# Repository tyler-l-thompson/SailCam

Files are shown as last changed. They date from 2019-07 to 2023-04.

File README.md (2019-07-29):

# Description

The SailCam is an attempt to put an entirly self sufficent camera on a sail boat. The camera mounts to the stern rail of the boat and does not require an external power source. It powers itself entirely from solar energy and a battery pack.

The current design sacrifices elegance for modularity and brute force functionality. It is divided into components that can be individually detached and redesigned if needed. This allows for design iteration over a testing period. A new design will be created after core functionality is refined. 

# Video Results

All timelapse videos processed from the pictures taken by the SailCam can be found [here](https://photos.app.goo.gl/NxdoZSaHQNxRXsou5)

## Port Huron to Mackinac Race 2019
https://youtu.be/PzzFX_mOYdo

# Specifications

Battery Capacity: 33600 mAh <br>
Solar Panel Output (Per panel): 4V 400mA <br>
Image Capture Interval: 20 seconds <br>
Storage Capacity: up to 32 GB <br>

# Parts
Camera Module: ArduCAM Mini 5MP Plus OV5642 <br>
CPU: Arduino Mini Pro ATMega328 16MHz 3.3V <br>
SD Card Module: LC Studio SPI SD Card Socket Reader/Writer <br>
Real Time Clock: DS3231 <br>
Power Controller: TP4056 <br>
Batteries: 14500 3.7V 2800mAH Lithium Li-ion

# Build
## Main Board
Front of the main board without the SD card module attached<br>

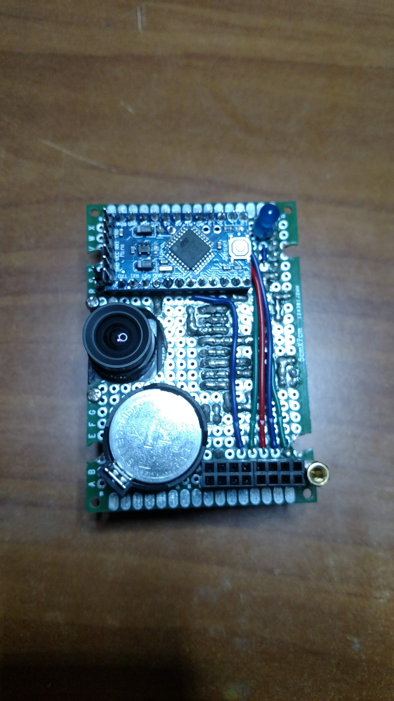
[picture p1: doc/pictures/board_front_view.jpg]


Back of the main board<br>

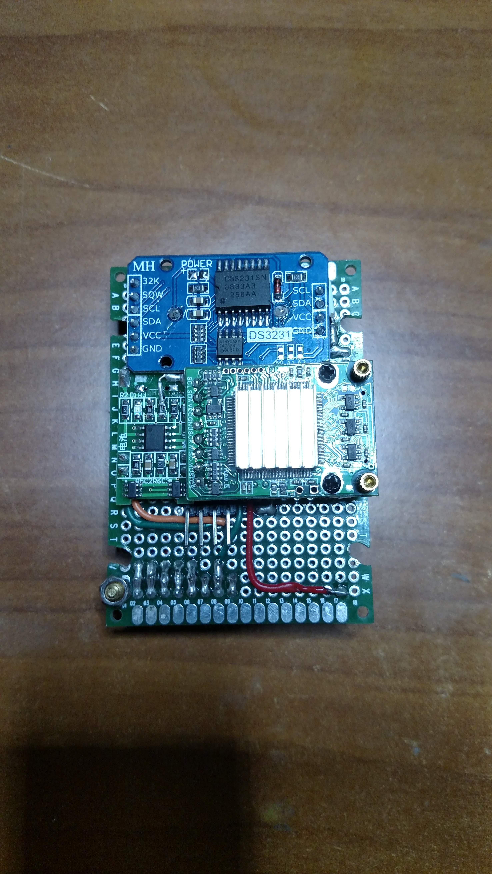
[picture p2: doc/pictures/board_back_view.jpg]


Side view<br>

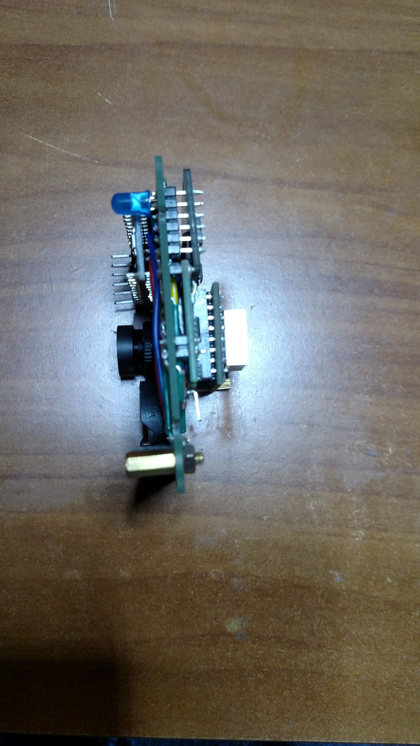
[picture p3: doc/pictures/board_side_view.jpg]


## Final Construction
Final Construction for the 2019 Mackinac Race. A lot of the chassis was 3D printed. Originally the camera module was designed to be in potrait mode, but after testing, it was changed to landscape.
<br>

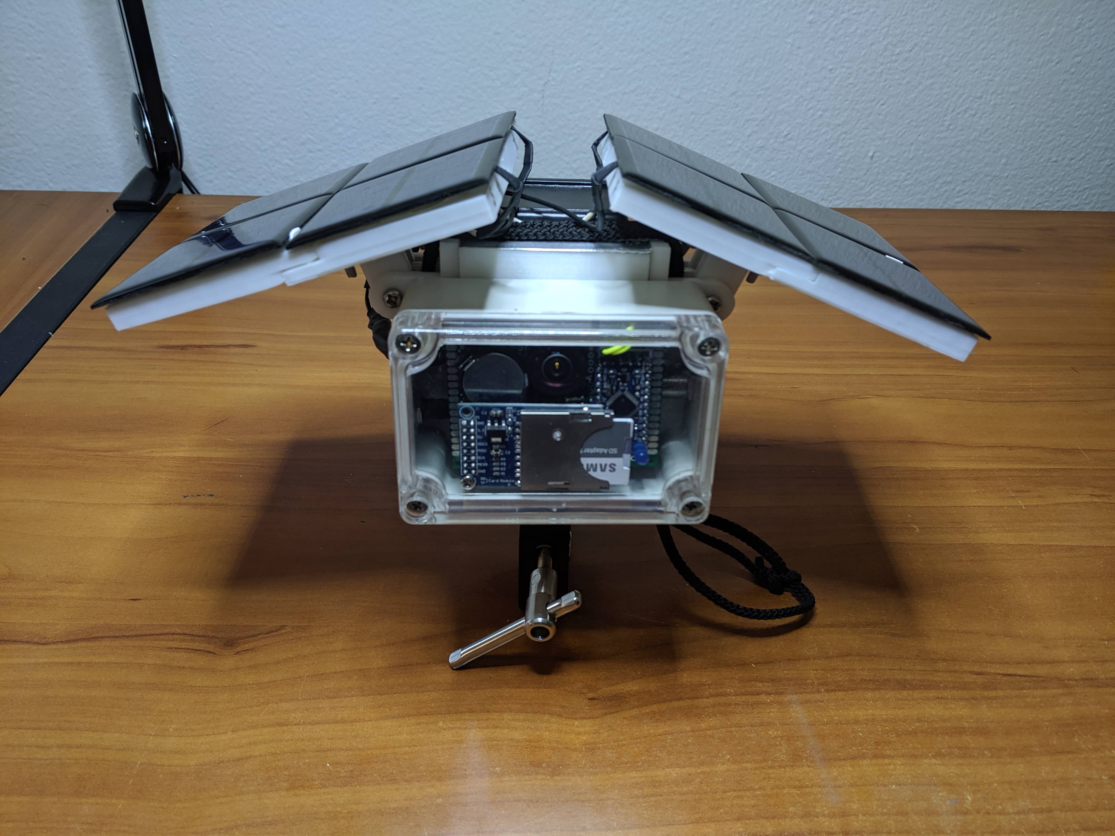
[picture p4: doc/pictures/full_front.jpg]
<br>
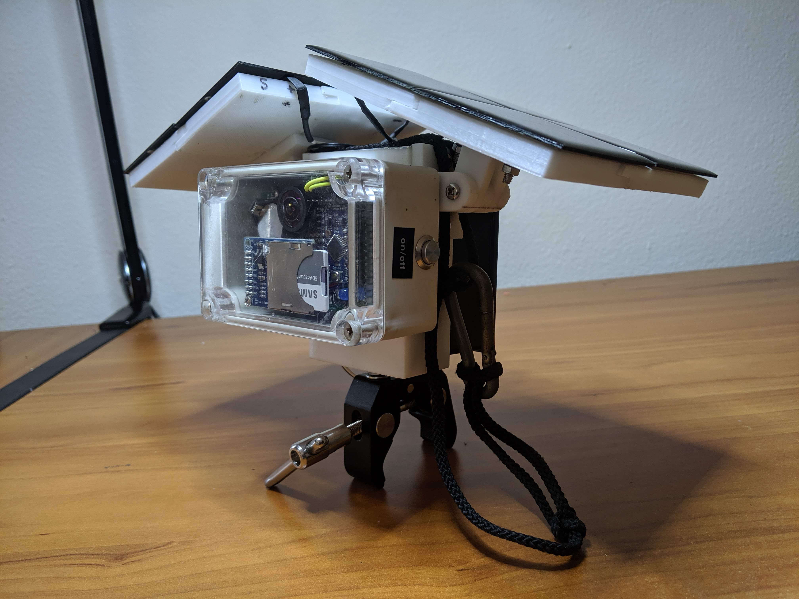
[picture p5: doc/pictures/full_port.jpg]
<br>
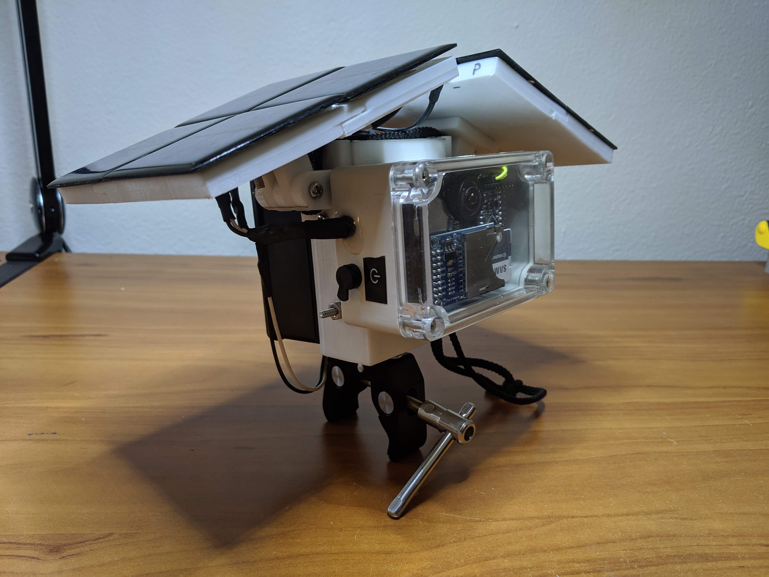
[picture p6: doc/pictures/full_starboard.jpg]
<br>

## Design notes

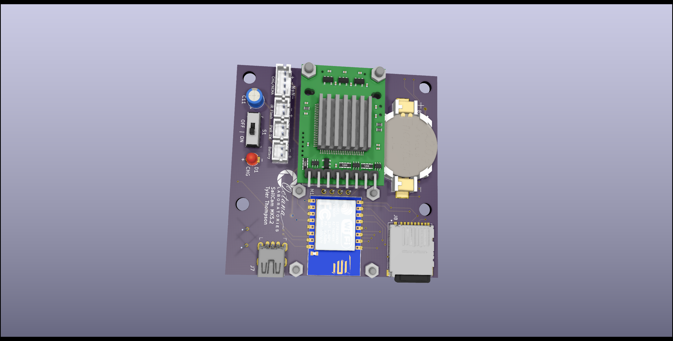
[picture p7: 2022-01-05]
doc/pictures/SailCam_MK5_back.png

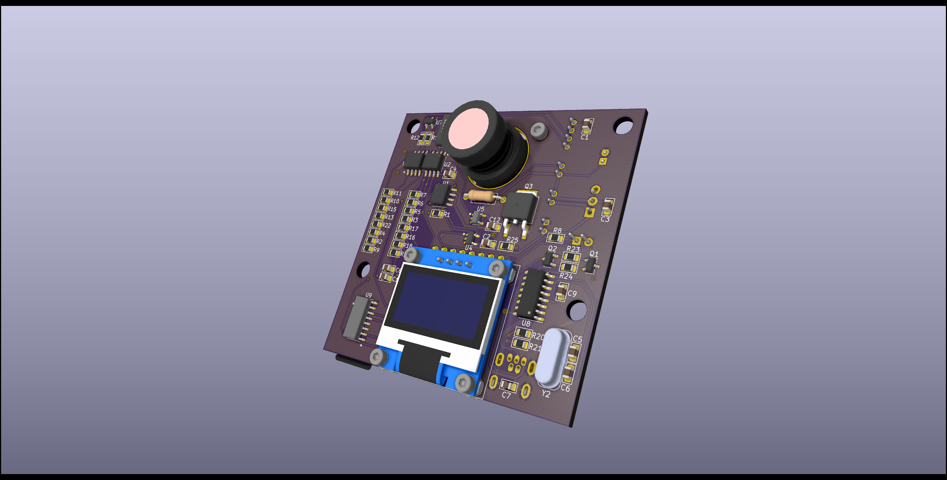
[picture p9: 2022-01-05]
doc/pictures/SailCam_MK5_front.png

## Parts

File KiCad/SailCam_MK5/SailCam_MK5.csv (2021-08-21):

Source: | C:\Users\Dexter\Documents\SailCam_MK5\SailCam_MK5\SailCam_MK5.sch
Date: | 8/5/2021 7:54:40 PM
Tool: | Eeschema (5.1.5)-3
Component Count: | 66
Ref | Value | Footprint | Datasheet | Manufacturer | Vendor
B1 | BU2032SM-BT-GTR | footprints:BAT_BU2032SM-BT-GTR | https://media.digikey.com/pdf/Data%20Sheets/Memory%20Protection%20PDFs/Coin_Cell_Guide.pdf
C1 | 0.33 uF | footprints:C_0805_2012Metric_Pad1.15x1.40mm_HandSolder_FullSilk | ~
C2 | 1 uF | footprints:C_0805_2012Metric_Pad1.15x1.40mm_HandSolder_FullSilk | ~
C3 | 10 uF | footprints:C_0805_2012Metric_Pad1.15x1.40mm_HandSolder_FullSilk | ~
C4 | 10 uF | footprints:C_0805_2012Metric_Pad1.15x1.40mm_HandSolder_FullSilk | ~
C5 | 22 pF | footprints:C_0805_2012Metric_Pad1.15x1.40mm_HandSolder_FullSilk | ~
C6 | 22 pF | footprints:C_0805_2012Metric_Pad1.15x1.40mm_HandSolder_FullSilk | ~
C7 | 0.1 uF | footprints:C_0805_2012Metric_Pad1.15x1.40mm_HandSolder_FullSilk | ~
C8 | 0.1 uF | footprints:C_0805_2012Metric_Pad1.15x1.40mm_HandSolder_FullSilk | ~
C9 | 0.1 uF | footprints:C_0805_2012Metric_Pad1.15x1.40mm_HandSolder_FullSilk | ~
C10 | 0.1 uF | footprints:C_0805_2012Metric_Pad1.15x1.40mm_HandSolder_FullSilk | ~
C11 | 100 uF | Capacitor_THT:CP_Radial_D5.0mm_P2.00mm | ~
C12 | 0.1 uF | footprints:C_0805_2012Metric_Pad1.15x1.40mm_HandSolder_FullSilk | ~
D1 | LED | LED_THT:LED_D3.0mm | ~
J1 | B2B-PH-K-SLFSN | footprints:B2B-PH-K-SLFSN | https://www.jst-mfg.com/product/pdf/eng/ePH.pdf
J2 | B2B-PH-K-SLFSN | footprints:B2B-PH-K-SLFSN | https://www.jst-mfg.com/product/pdf/eng/ePH.pdf
J3 | B2B-PH-K-SLFSN | footprints:B2B-PH-K-SLFSN | https://www.jst-mfg.com/product/pdf/eng/ePH.pdf
J4 | B4B-PH-K-SLFSN | footprints:B4B-PH-K-SLFSN | https://www.jst-mfg.com/product/pdf/eng/ePH.pdf
J5 | SSW-108-02-G-S | footprints:SSW-108-02-G-S | https://www.uctronics.com/download/Amazon/B0068.pdf
J6 | SSW-104-02-G-S | footprints:SSW-104-02-G-S_OLED | http://suddendocs.samtec.com/catalog_english/ssw_th.pdf
J7 | USB_B | footprints:AMPHENOL_61729-1011BLF | https://www.amphenol-icc.com/media/wysiwyg/files/drawing/61729.pdf
J8 | DM3BT-DSF-PEJS | footprints:DM3BT-DSF-PEJS | https://www.hirose.com/product/document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
M1 | 2491 | digikey-footprints:WIFI_Module_ESP8266_2491 | https://media.digikey.com/pdf/Data%20Sheets/Adafruit%20PDFs/2491_Web.pdf | Adafruit Industries LLC
Q1 | SS8050-G | footprints:SS8050-G | https://www.digikey.com/en/htmldatasheets/production/1953165/0/0/1/ss8050-g.html
Q2 | SS8050-G | footprints:SS8050-G | https://www.digikey.com/en/htmldatasheets/production/1953165/0/0/1/ss8050-g.html
Q3 | AOD1N60 | TO228P1003X240-3N
R1 | 320 KΩ | footprints:C_0805_2012Metric_Pad1.15x1.40mm_HandSolder_FullSilk | ~
R2 | 100 KΩ | footprints:C_0805_2012Metric_Pad1.15x1.40mm_HandSolder_FullSilk | ~
R3 | 320 KΩ | footprints:C_0805_2012Metric_Pad1.15x1.40mm_HandSolder_FullSilk | ~
R4 | 100 KΩ | footprints:C_0805_2012Metric_Pad1.15x1.40mm_HandSolder_FullSilk | ~
R5 | 1 KΩ | footprints:C_0805_2012Metric_Pad1.15x1.40mm_HandSolder_FullSilk | ~
R6 | 1 KΩ | footprints:C_0805_2012Metric_Pad1.15x1.40mm_HandSolder_FullSilk | ~
R7 | 1 KΩ | footprints:C_0805_2012Metric_Pad1.15x1.40mm_HandSolder_FullSilk | ~
R8 | 1k Ω | footprints:C_0805_2012Metric_Pad1.15x1.40mm_HandSolder_FullSilk | ~
R9 | 3 KΩ | footprints:C_0805_2012Metric_Pad1.15x1.40mm_HandSolder_FullSilk | ~
R10 | 10 KΩ | footprints:C_0805_2012Metric_Pad1.15x1.40mm_HandSolder_FullSilk | ~
R11 | 10 KΩ | footprints:C_0805_2012Metric_Pad1.15x1.40mm_HandSolder_FullSilk | ~
R12 | 10 Ω | footprints:C_0805_2012Metric_Pad1.15x1.40mm_HandSolder_FullSilk | ~
R13 | 330 Ω | footprints:C_0805_2012Metric_Pad1.15x1.40mm_HandSolder_FullSilk | ~
R14 | 10 Ω | footprints:C_0805_2012Metric_Pad1.15x1.40mm_HandSolder_FullSilk | ~
R15 | 330 Ω | footprints:C_0805_2012Metric_Pad1.15x1.40mm_HandSolder_FullSilk | ~
R16 | 10 KΩ | footprints:C_0805_2012Metric_Pad1.15x1.40mm_HandSolder_FullSilk | ~
R17 | 10 KΩ | footprints:C_0805_2012Metric_Pad1.15x1.40mm_HandSolder_FullSilk | ~
R18 | 10 KΩ | footprints:C_0805_2012Metric_Pad1.15x1.40mm_HandSolder_FullSilk | ~
R19 | 10 KΩ | footprints:C_0805_2012Metric_Pad1.15x1.40mm_HandSolder_FullSilk | ~
R20 | 470 Ω | footprints:C_0805_2012Metric_Pad1.15x1.40mm_HandSolder_FullSilk | ~
R21 | 470 Ω | footprints:C_0805_2012Metric_Pad1.15x1.40mm_HandSolder_FullSilk | ~
R22 | 10 KΩ | footprints:C_0805_2012Metric_Pad1.15x1.40mm_HandSolder_FullSilk | ~
R23 | 10 KΩ | footprints:C_0805_2012Metric_Pad1.15x1.40mm_HandSolder_FullSilk | ~
R24 | 10 KΩ | footprints:C_0805_2012Metric_Pad1.15x1.40mm_HandSolder_FullSilk | ~
R25 | 1 KΩ | footprints:C_0805_2012Metric_Pad1.15x1.40mm_HandSolder_FullSilk | ~
R26 | 10 KΩ | Resistor_THT:R_Box_L8.4mm_W2.5mm_P5.08mm | ~
S1 | SW_SPST | digikey-footprints:Switch_Toggle_ATE1D-2M3-10-Z | ~
S2 | SW_Push | Button_Switch_THT:SW_PUSH_6mm | ~
S3 | SW_Push | Button_Switch_THT:SW_PUSH_6mm | ~
U1 | ADA4806-1ARJZ-R7 | footprints:ADA4806-1ARJZ-R7 | https://www.analog.com/media/en/technical-documentation/data-sheets/ADA4806-1.pdf
U2 | DS1672S-33+T&R | footprints:DS1672S-33&plus_T&R | https://datasheets.maximintegrated.com/en/ds/DS1672.pdf
U3 | NCV7805BD2TG | footprints:NCV7805BD2TG | https://www.onsemi.com/pdf/datasheet/mc7800-d.pdf
U4 | LTC4054ES5-4.2#TRMPBF | footprints:SOT95P280X100-5N | https://www.analog.com/media/en/technical-documentation/data-sheets/405442xf.pdf
U5 | XC6220B331MR-G | footprints:XC6220B331MR-G | https://media.digikey.com/pdf/Data%20Sheets/Torex/XC6220.pdf
U6 | MAX485CSA+ | footprints:MAX485CSA&plus_ | https://datasheets.maximintegrated.com/en/ds/MAX1487-MAX491.pdf
U7 | SM712.TCT | footprints:SM712.TCT | https://semtech.my.salesforce.com/sfc/p/
U8 | CH340G | Package_SO:SOIC-16_3.9x9.9mm_P1.27mm | http://www.datasheet5.com/pdf-local-2195953
U9 | MC74HC365ADG | footprints:MC74HC365ADG | https://www.onsemi.com/pdf/datasheet/mc74hc365a-d.pdf
Y1 | ABS25-32.768KHZ-6-1-T | footprints:XTAL_ABS25-32.768KHZ-6-1-T | https://abracon.com/Resonators/abs25.pdf
Y2 | ECS-120-20-4X | footprints:XTAL_ECS-120-20-4X | https://ecsxtal.com/store/pdf/hc-49usx.pdf

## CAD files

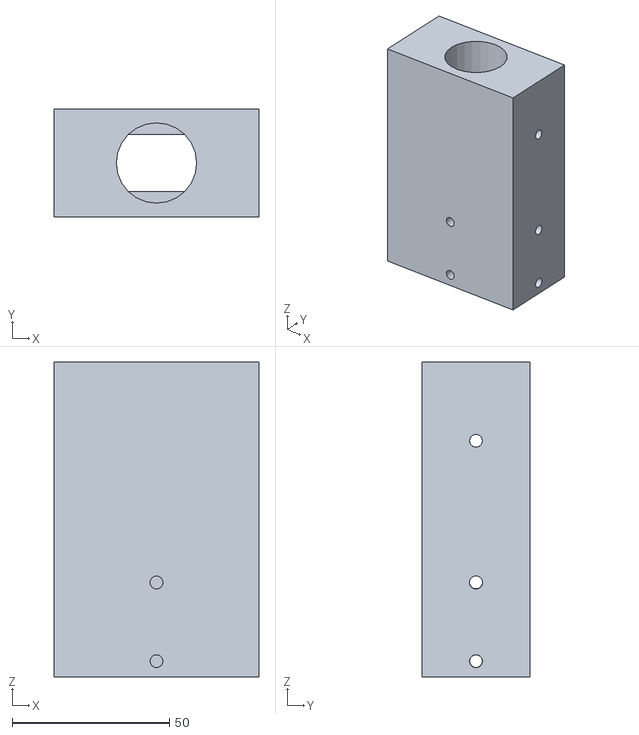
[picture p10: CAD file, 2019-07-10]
3D_Objects/main_bracket.stl
65.1 x 34.2 x 100.1

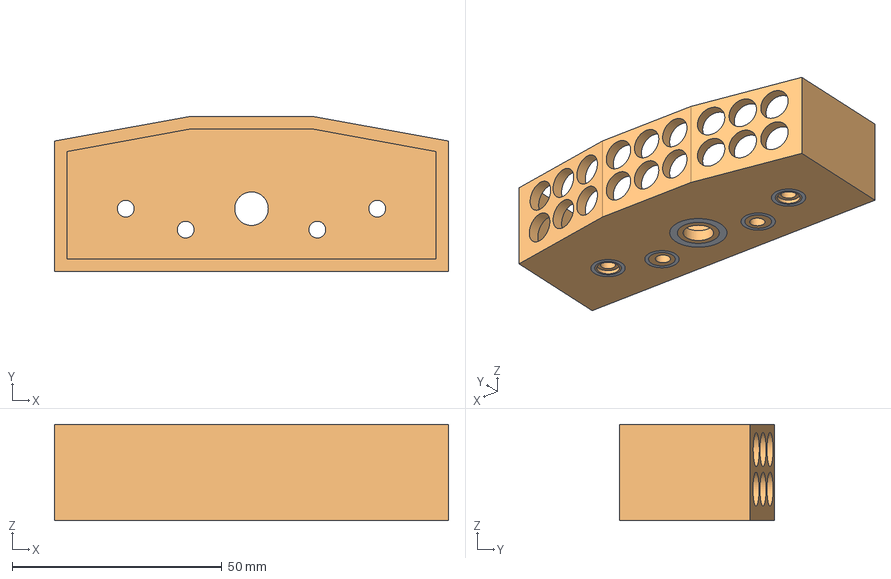
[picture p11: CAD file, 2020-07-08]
3D_Objects/ir_mount/ir_mount_base_v2.FCStd
94.0 x 37.0 x 23.0 mm

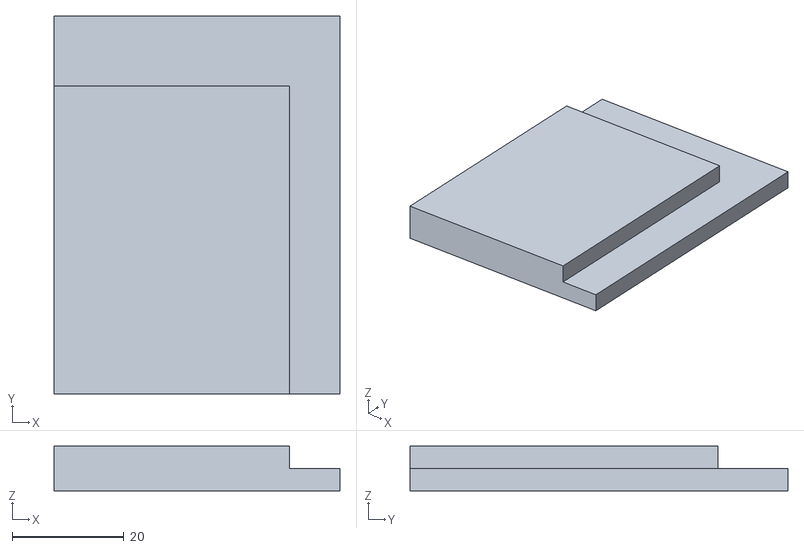
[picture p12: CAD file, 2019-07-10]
3D_Objects/panel_mount/section_2.stl
51.0 x 67.5 x 8.00

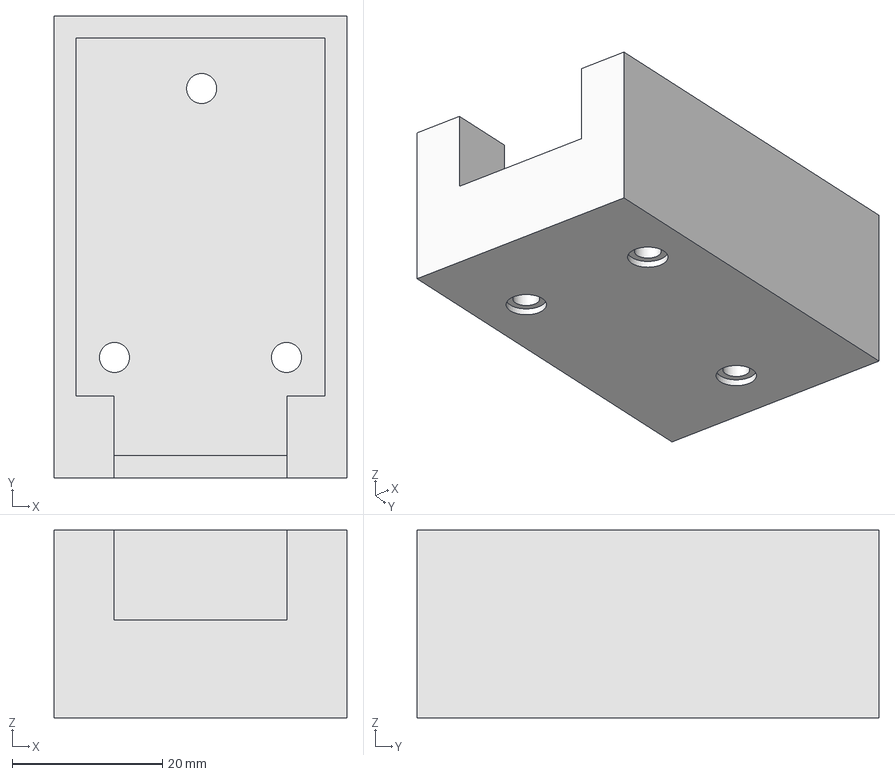
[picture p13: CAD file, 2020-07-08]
3D_Objects/power_supply/12v_stepper_case.FCStd
39.0 x 61.5 x 25.0 mm

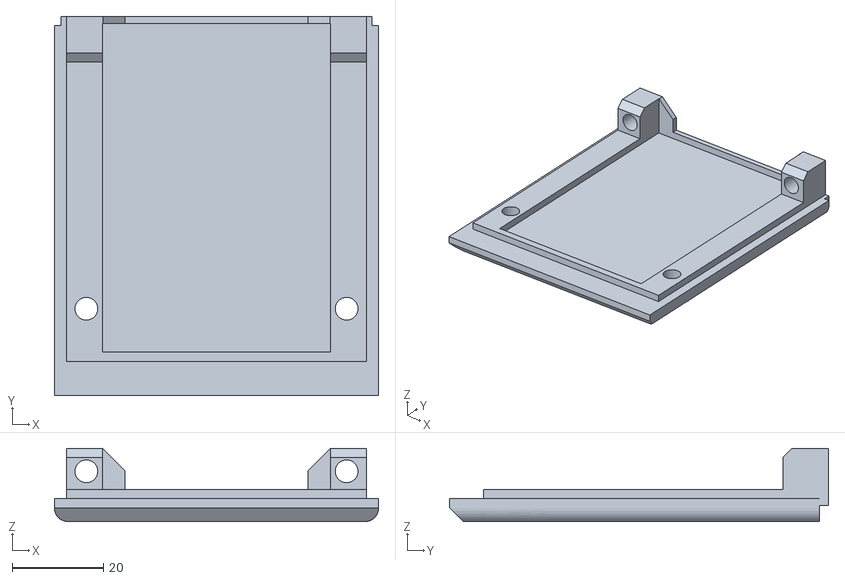
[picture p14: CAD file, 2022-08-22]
3D_Objects/SailCam_MK5/SailCamMK5_BoatCase_Back.stl
71.0 x 83.0 x 16.0

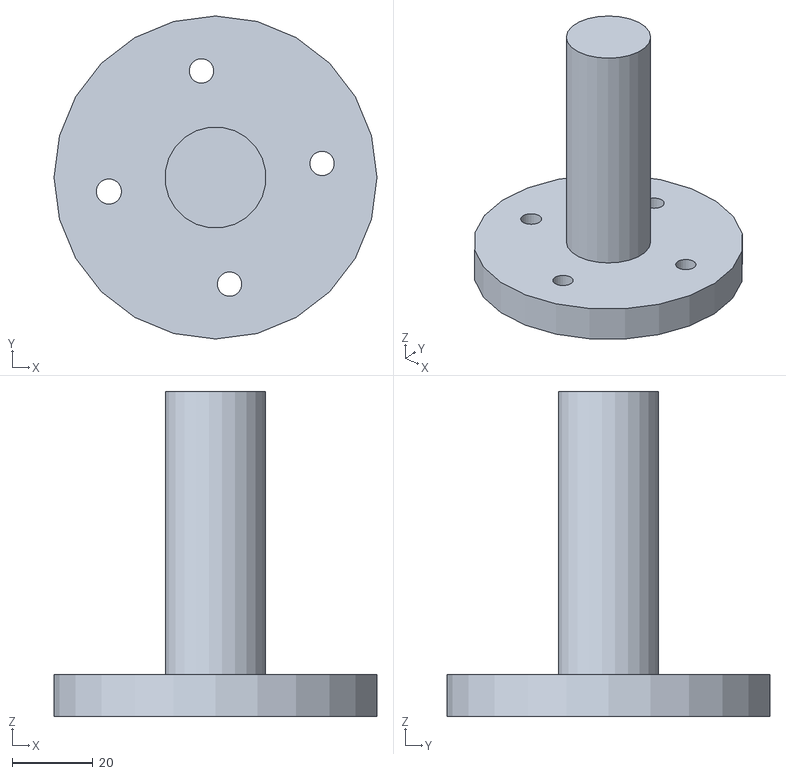
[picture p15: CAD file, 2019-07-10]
3D_Objects/stand_bracket.stl
80.1 x 80.1 x 80.6

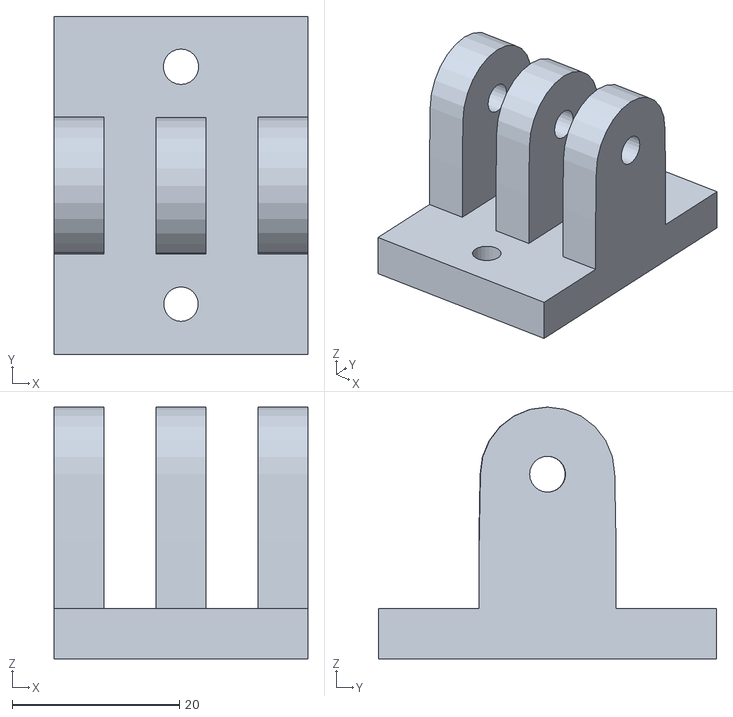
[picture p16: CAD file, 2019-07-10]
3D_Objects/bracket_bottom_v2.stl
30.3 x 40.4 x 30.1

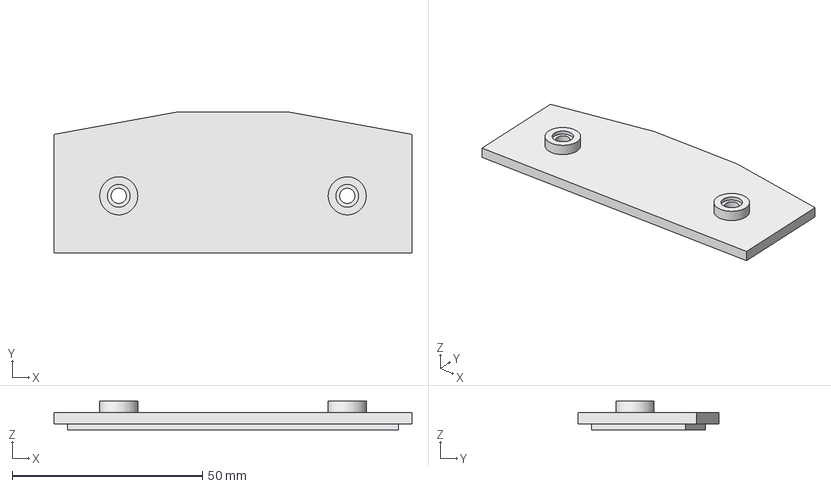
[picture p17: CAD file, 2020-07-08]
3D_Objects/ir_mount/ir_mount_cover.FCStd
94.0 x 37.0 x 7.50 mm

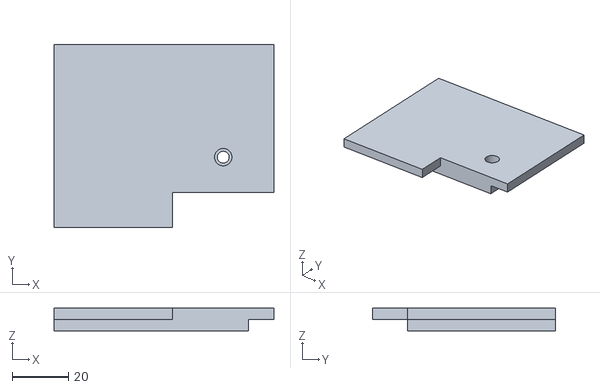
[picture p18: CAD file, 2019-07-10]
3D_Objects/panel_mount/section_3.stl
78.0 x 65.0 x 8.00

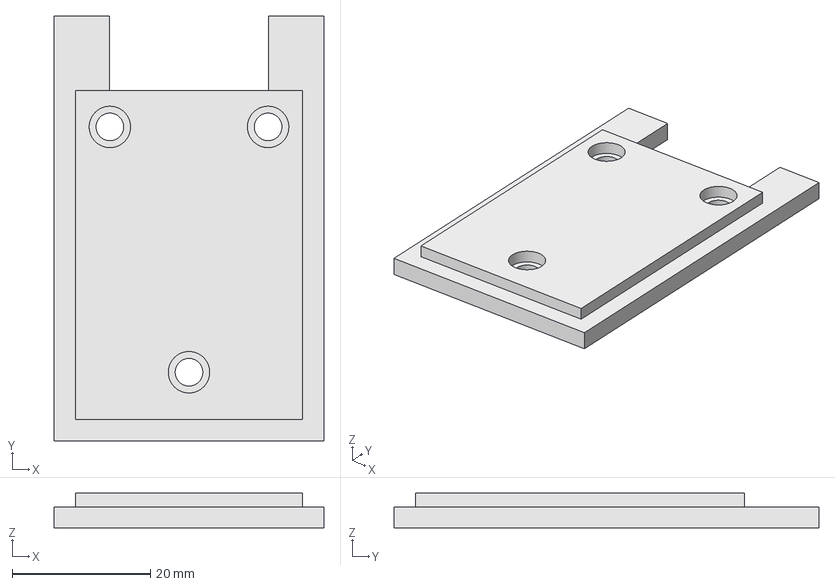
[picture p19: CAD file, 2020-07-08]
3D_Objects/power_supply/12v_stepper_case_lid.FCStd
39.0 x 61.5 x 5.00 mm

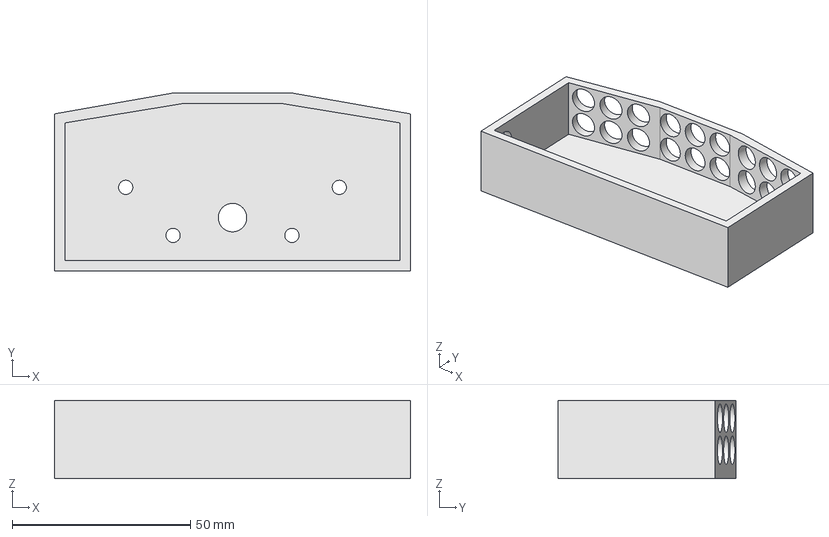
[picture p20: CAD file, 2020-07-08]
3D_Objects/ir_mount/ir_mount_base.FCStd
100.0 x 50.0 x 22.0 mm

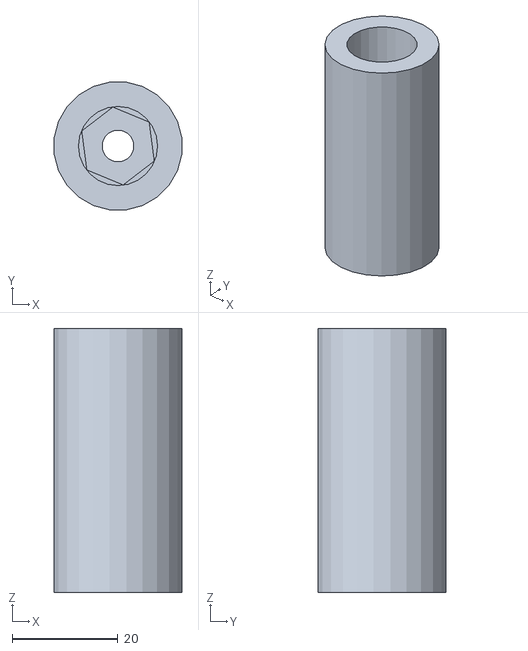
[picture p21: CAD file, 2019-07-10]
3D_Objects/mount_adapter.stl
24.2 x 24.2 x 50.0

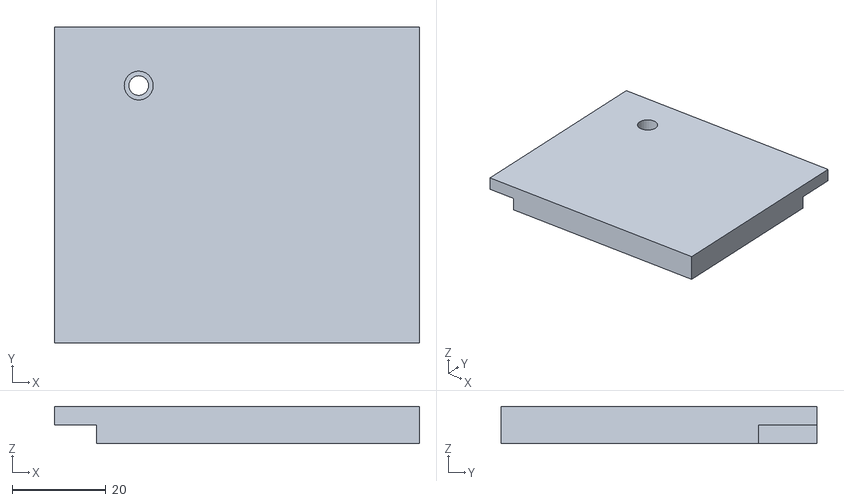
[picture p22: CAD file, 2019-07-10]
3D_Objects/panel_mount/section_1.stl
78.0 x 67.5 x 8.00

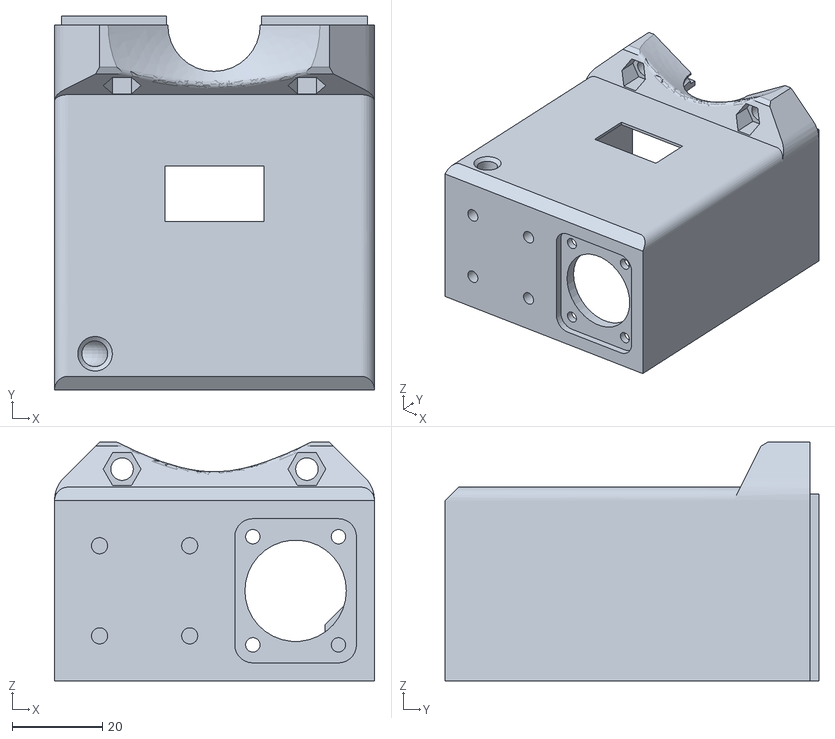
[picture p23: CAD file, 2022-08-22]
3D_Objects/SailCam_MK5/SailCamMK5_BoatCase_Bottom.stl
71.0 x 82.9 x 53.0

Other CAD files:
3D_Objects/SailCam_MK5/SailCamMK5_BoatCase_Back_Cutout.stl
3D_Objects/panel_mount/section_4.stl
3D_Objects/SailCam_MK5/SailCamMK5_BoatCase_Top.stl
3D_Objects/stand_bracket_post.stl
3D_Objects/SailCam_MK5/AAA Batterie.step
3D_Objects/SailCam_MK5/Button.FCStd
3D_Objects/SailCam_MK5/Button.step
3D_Objects/SailCam_MK5/Clamp.FCStd
3D_Objects/SailCam_MK5/Clamp.step
3D_Objects/SailCam_MK5/M3_10mm_Screw.step
3D_Objects/SailCam_MK5/M3_25mm_Screw.step
3D_Objects/SailCam_MK5/M3_6mm_Screw.step
3D_Objects/SailCam_MK5/M3_Nut.step
3D_Objects/SailCam_MK5/M3_Screw.FCStd
3D_Objects/SailCam_MK5/M4_12mm_Screw.step
3D_Objects/SailCam_MK5/M4_20mm_Screw.step
3D_Objects/SailCam_MK5/M4_24mm_Screw.step
3D_Objects/SailCam_MK5/M4_30mm_Screw.step
3D_Objects/SailCam_MK5/M4_40mm_Screw.step
3D_Objects/SailCam_MK5/M4_Nut.step
3D_Objects/SailCam_MK5/M4_Screw.FCStd
3D_Objects/SailCam_MK5/PowerConnector.FCStd
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

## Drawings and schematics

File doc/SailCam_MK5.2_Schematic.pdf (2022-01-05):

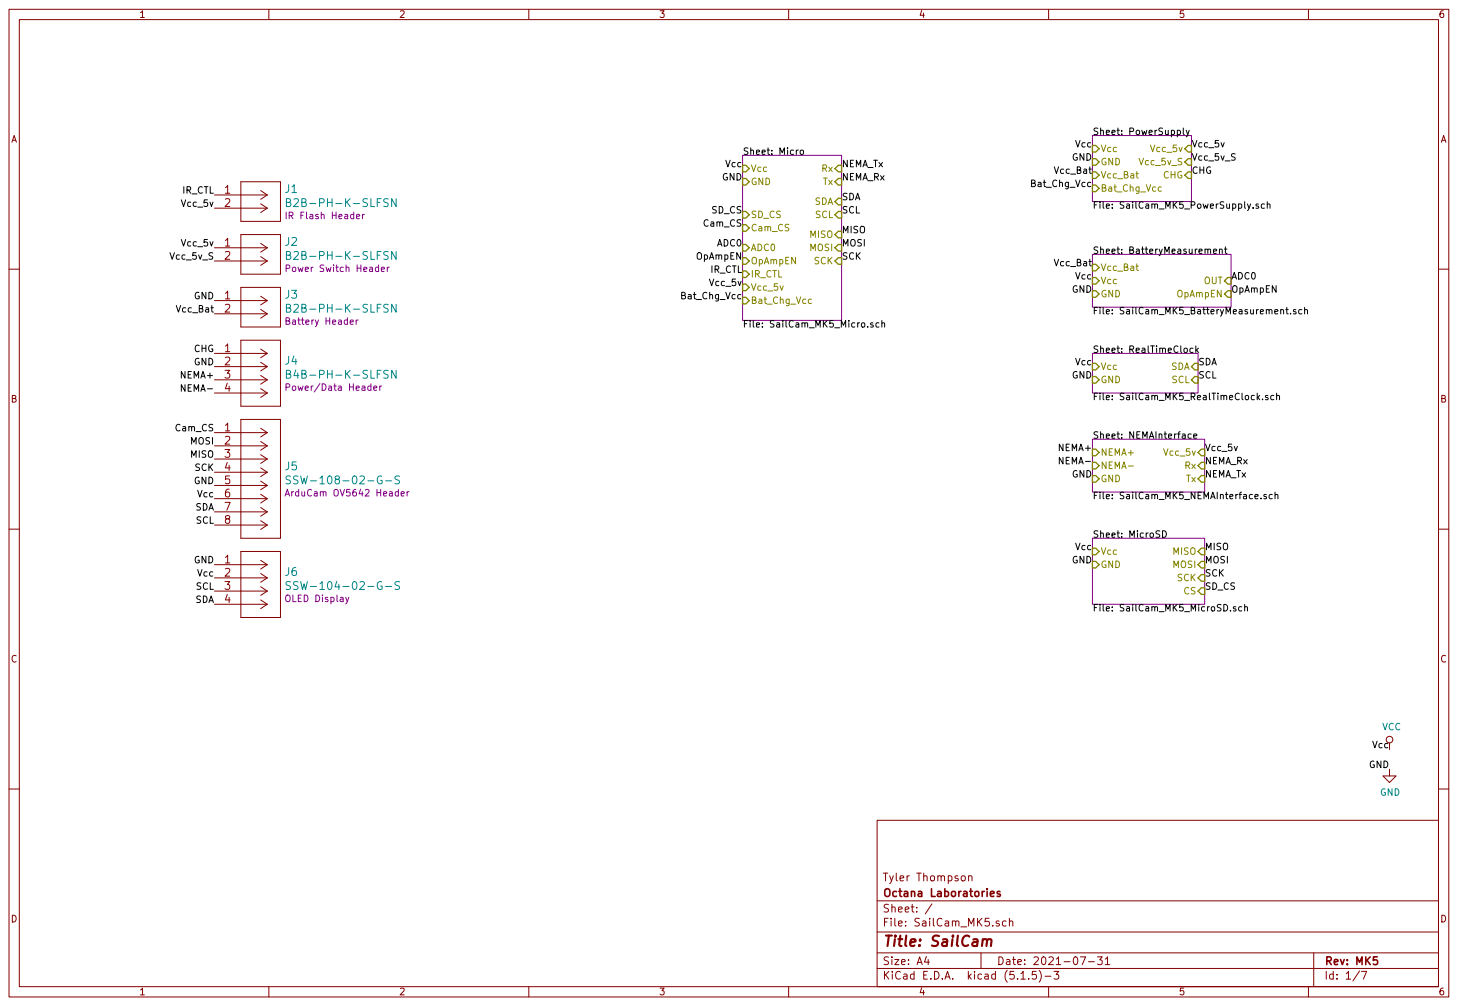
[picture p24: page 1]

Sheet: PowerSupply
File: SailCam_MK5_PowerSupply.sch Vcc GND

Sheet: Micro File: SailCam_MK5_Micro.sch Vcc GND
GND

Bat_Chg_Vcc Sheet: RealTimeClock File: SailCam_MK5_RealTimeClock.sch SDA

Vcc_5vRxTx NEMA+ NEMA- Sheet: MicroSD

File: SailCam_MK5.sch Sheet: / Octana Laboratories Tyler Thompson

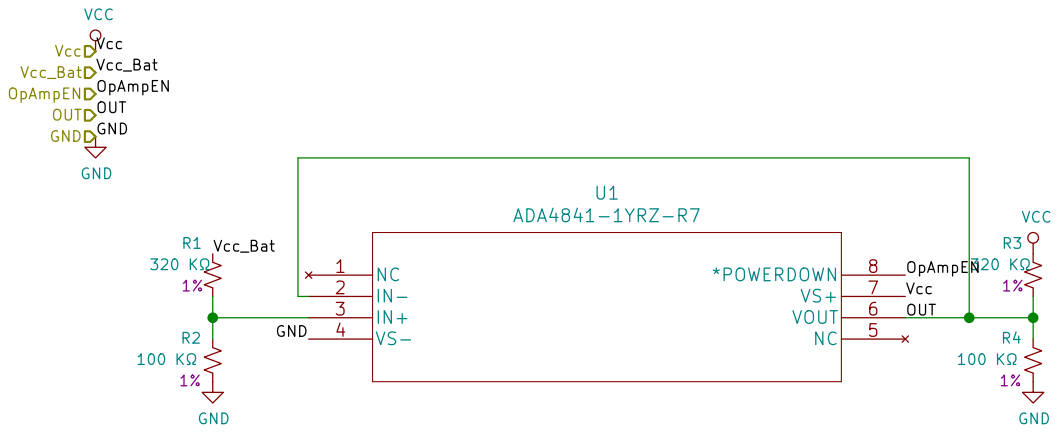
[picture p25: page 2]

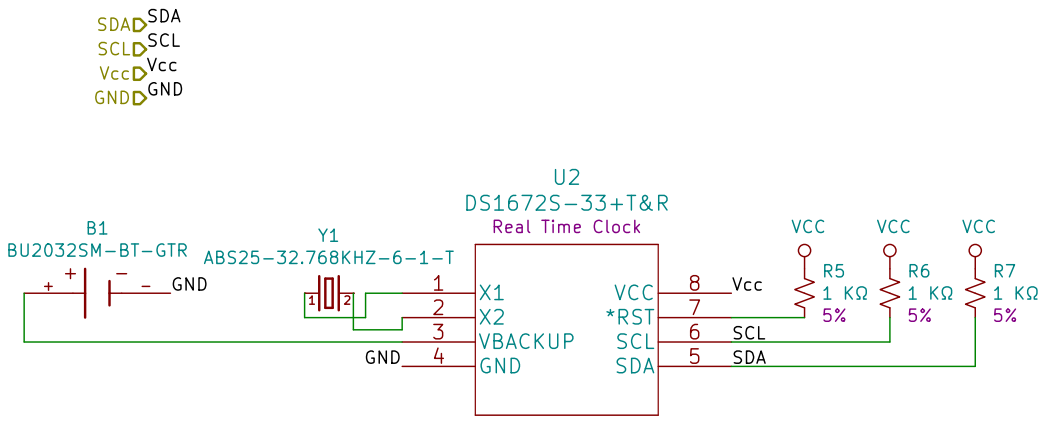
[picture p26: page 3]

File: SailCam_MK5_RealTimeClock.sch Sheet: /RealTimeClock/ Octana Laboratories Tyler Thompson

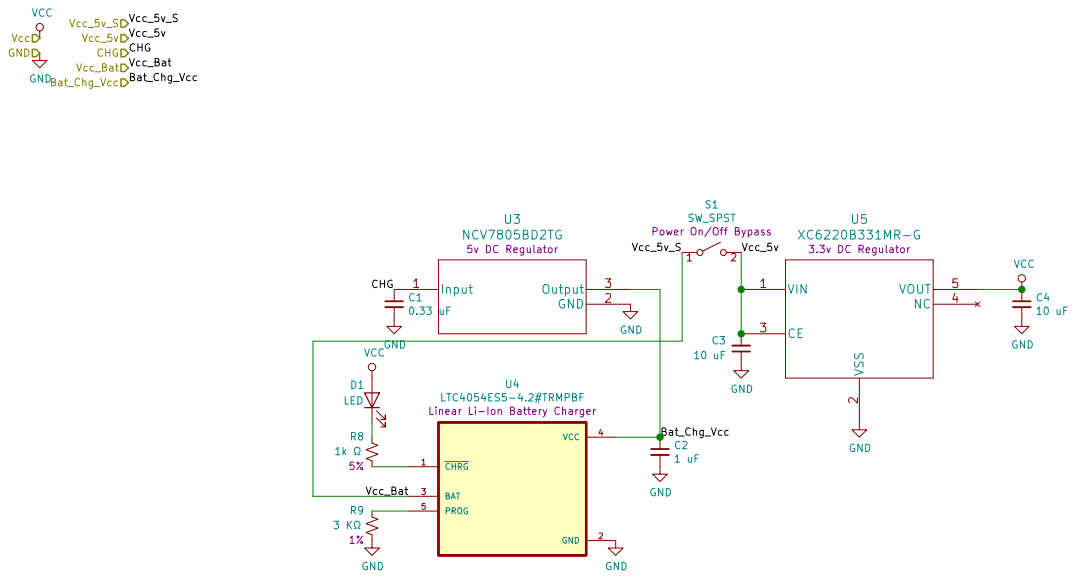
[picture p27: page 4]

Sheet: /PowerSupply/ Octana Laboratories Tyler Thompson GND GND

LED
Linear Li-Ion Battery Charger R8

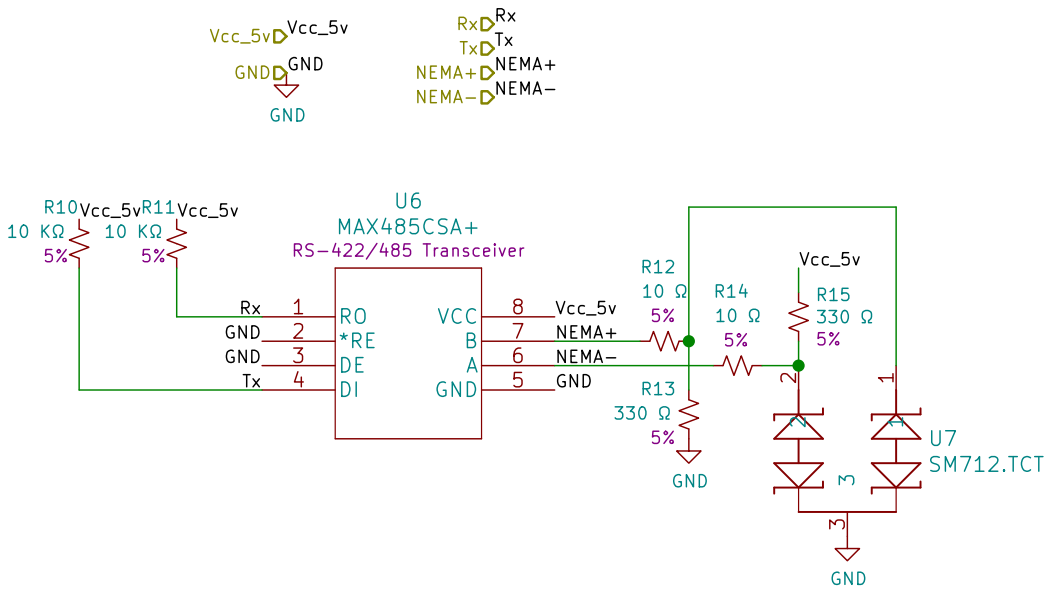
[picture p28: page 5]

File: SailCam_MK5_NEMAInterface.sch Sheet: /NEMAInterface/ Octana Laboratories Tyler Thompson

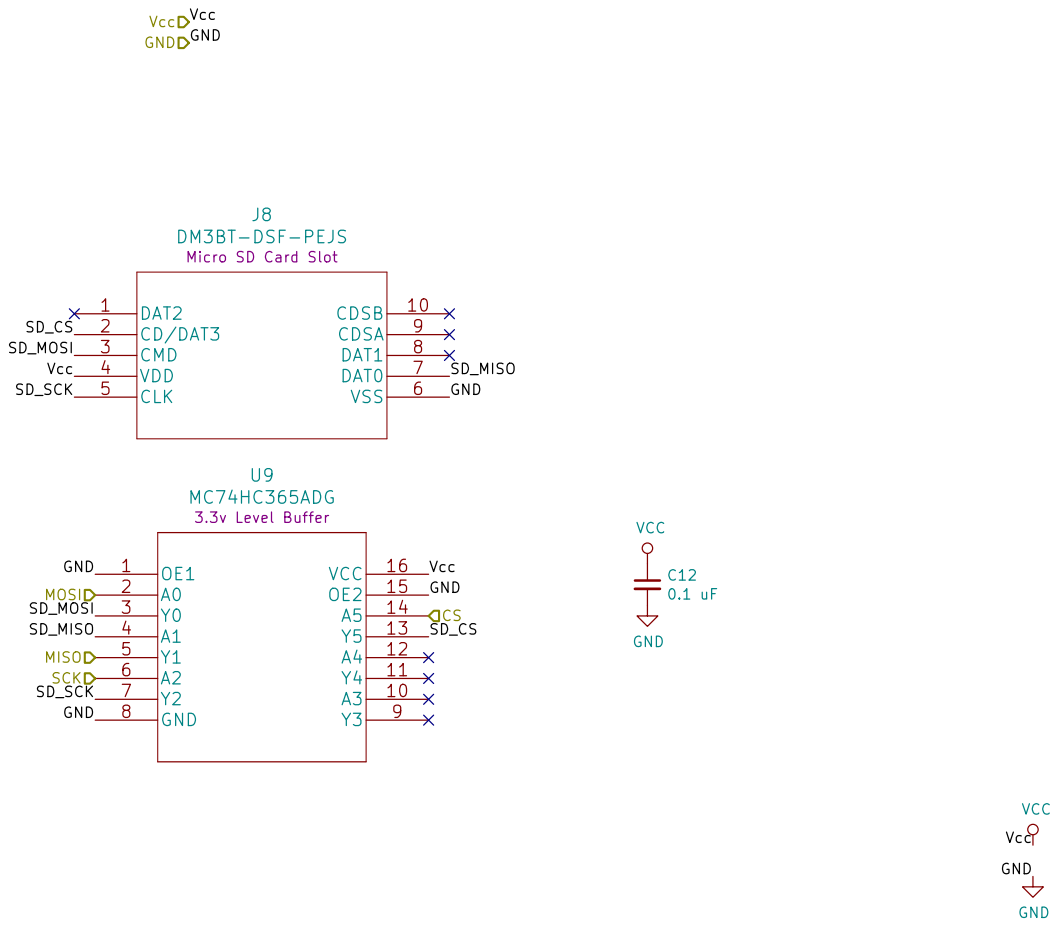
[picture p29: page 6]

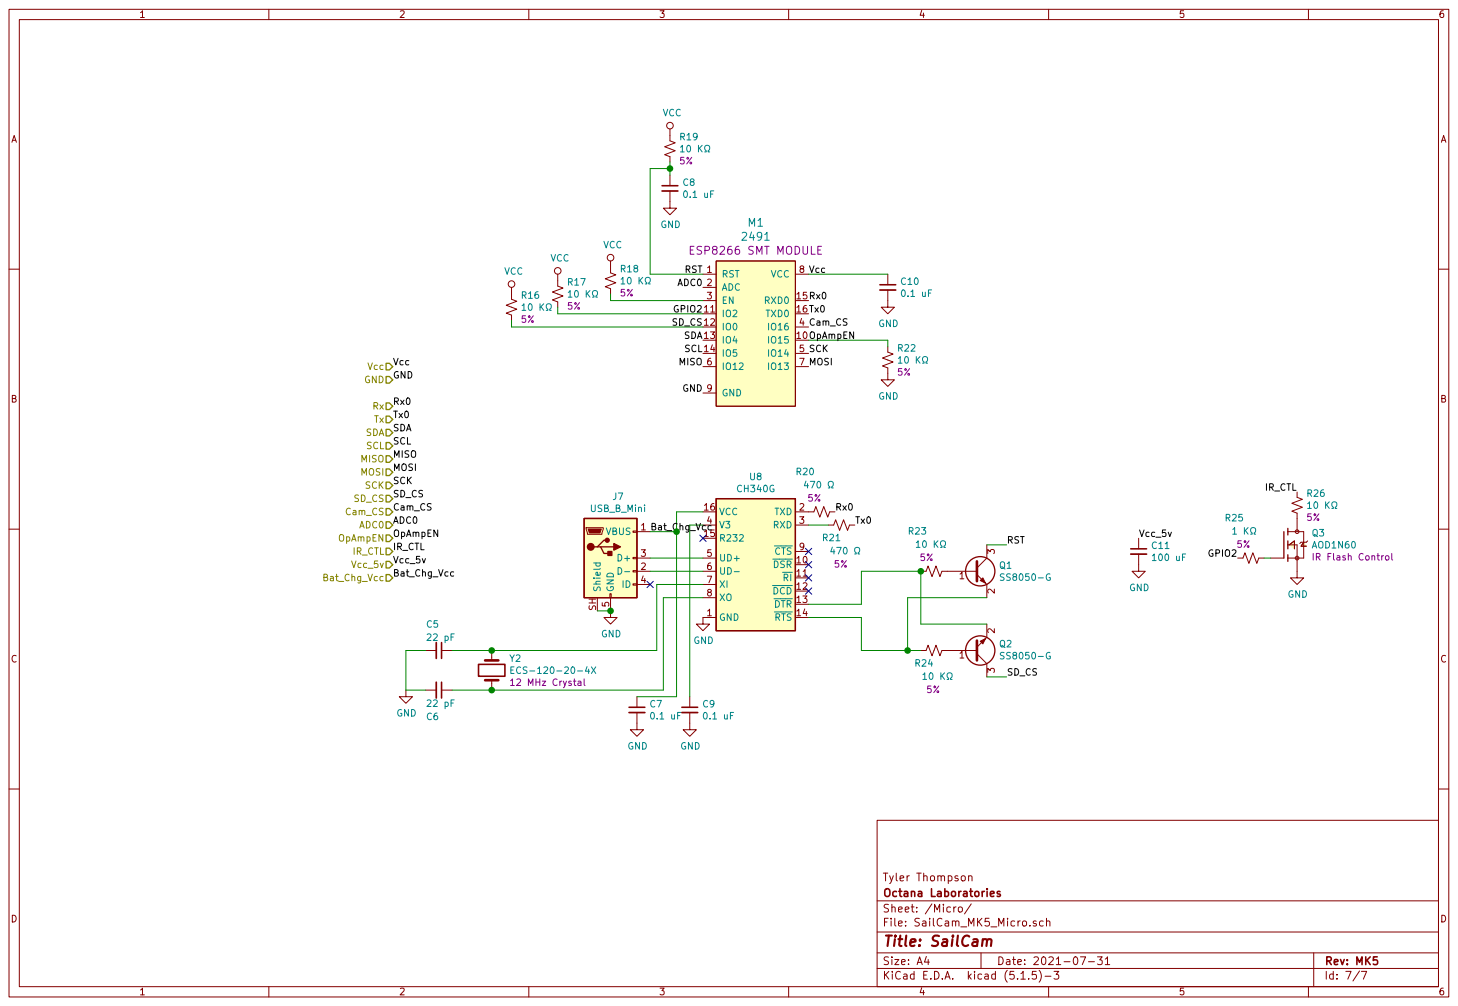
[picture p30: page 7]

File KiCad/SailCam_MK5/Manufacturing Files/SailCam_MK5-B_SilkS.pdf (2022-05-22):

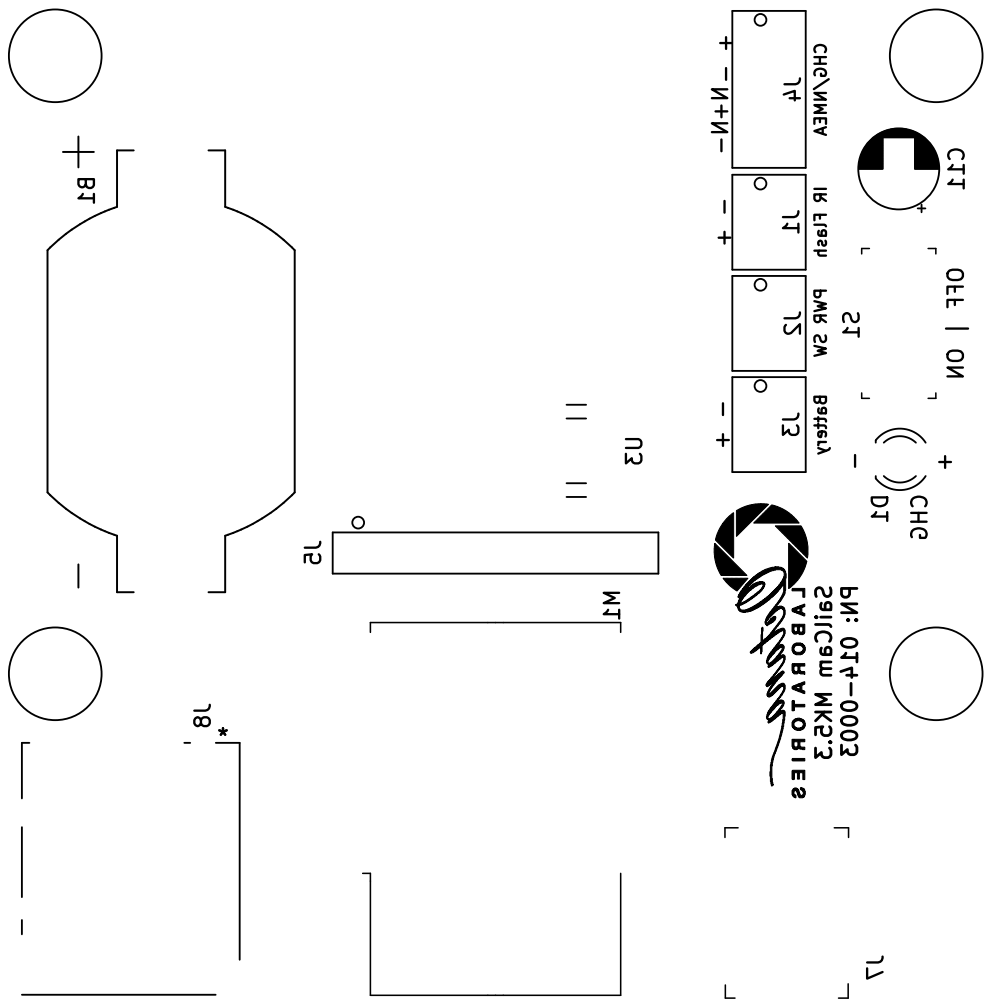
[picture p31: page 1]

SailCam MK5.3 PN: 014-0003 B1 J4 CHG/NMEA + - N+ N- J2 PWR SW J3 Battery+ - J1 IR Flash - + J7 U3 J5 M1 S1 OFF | ON D1 CHG + - C11 J8 *

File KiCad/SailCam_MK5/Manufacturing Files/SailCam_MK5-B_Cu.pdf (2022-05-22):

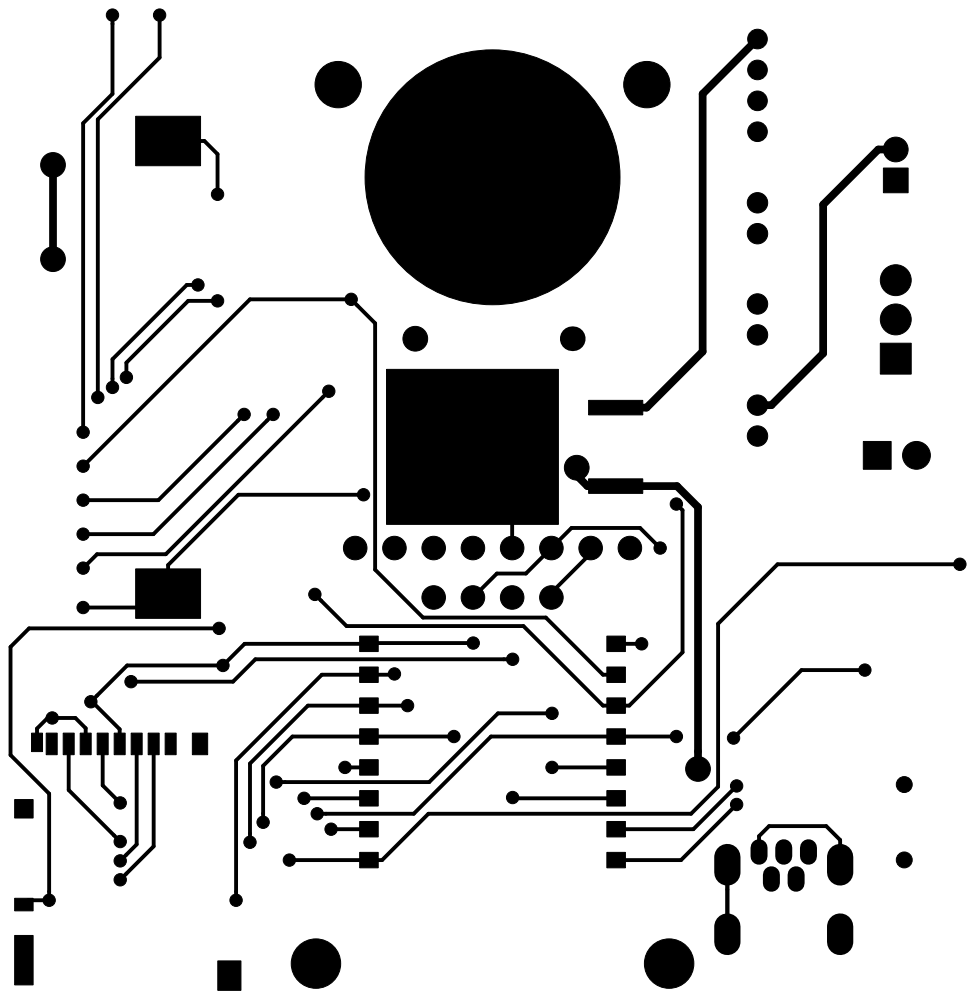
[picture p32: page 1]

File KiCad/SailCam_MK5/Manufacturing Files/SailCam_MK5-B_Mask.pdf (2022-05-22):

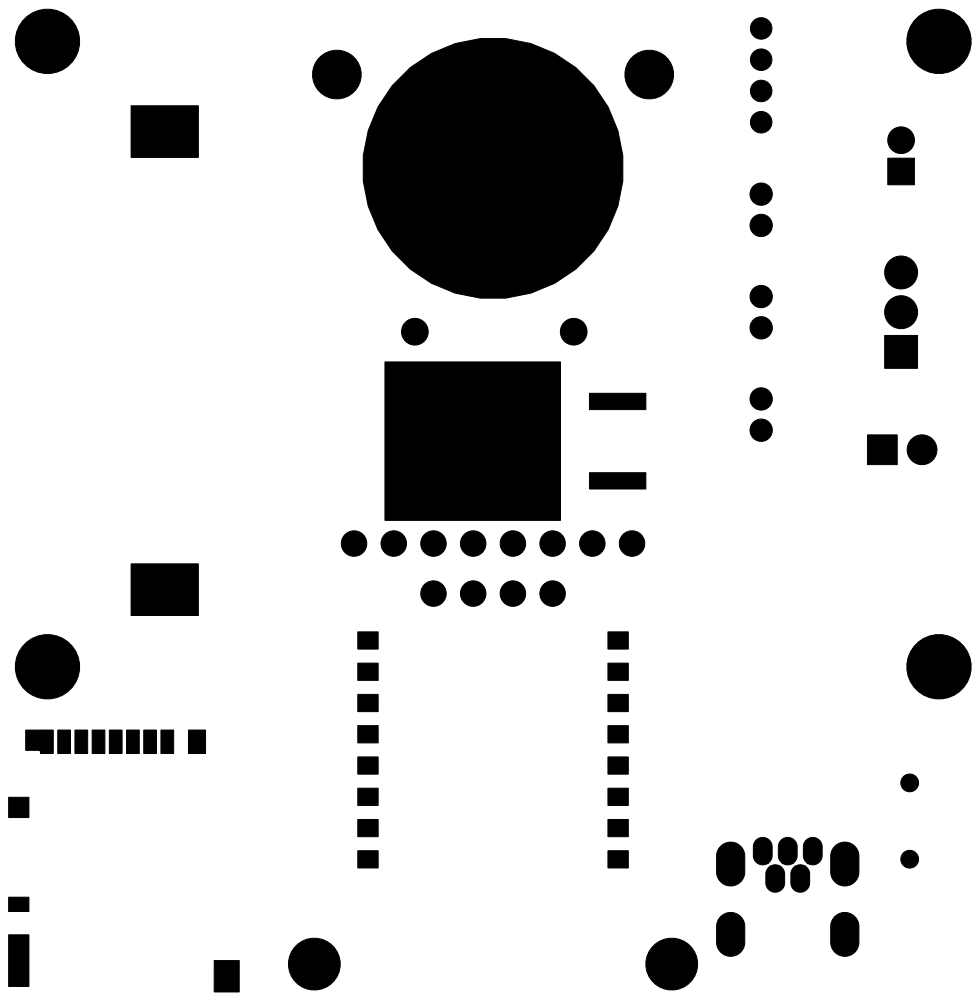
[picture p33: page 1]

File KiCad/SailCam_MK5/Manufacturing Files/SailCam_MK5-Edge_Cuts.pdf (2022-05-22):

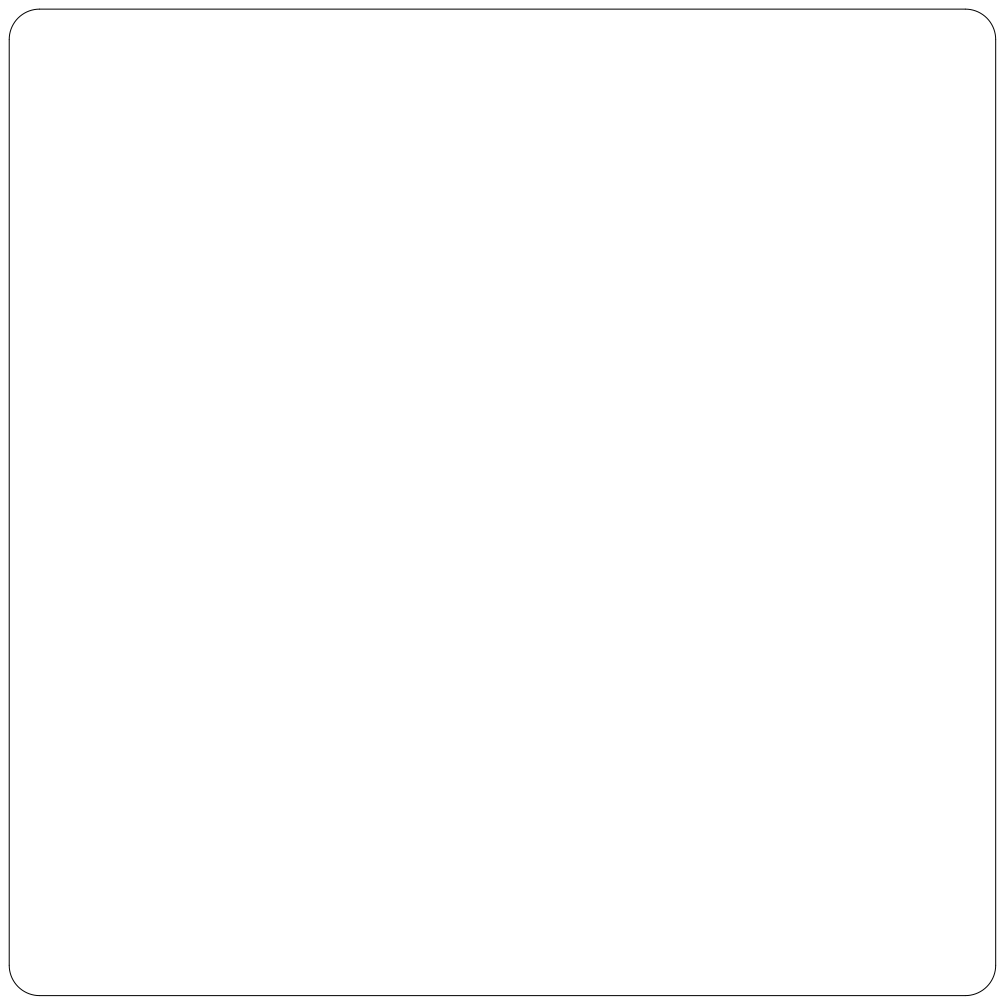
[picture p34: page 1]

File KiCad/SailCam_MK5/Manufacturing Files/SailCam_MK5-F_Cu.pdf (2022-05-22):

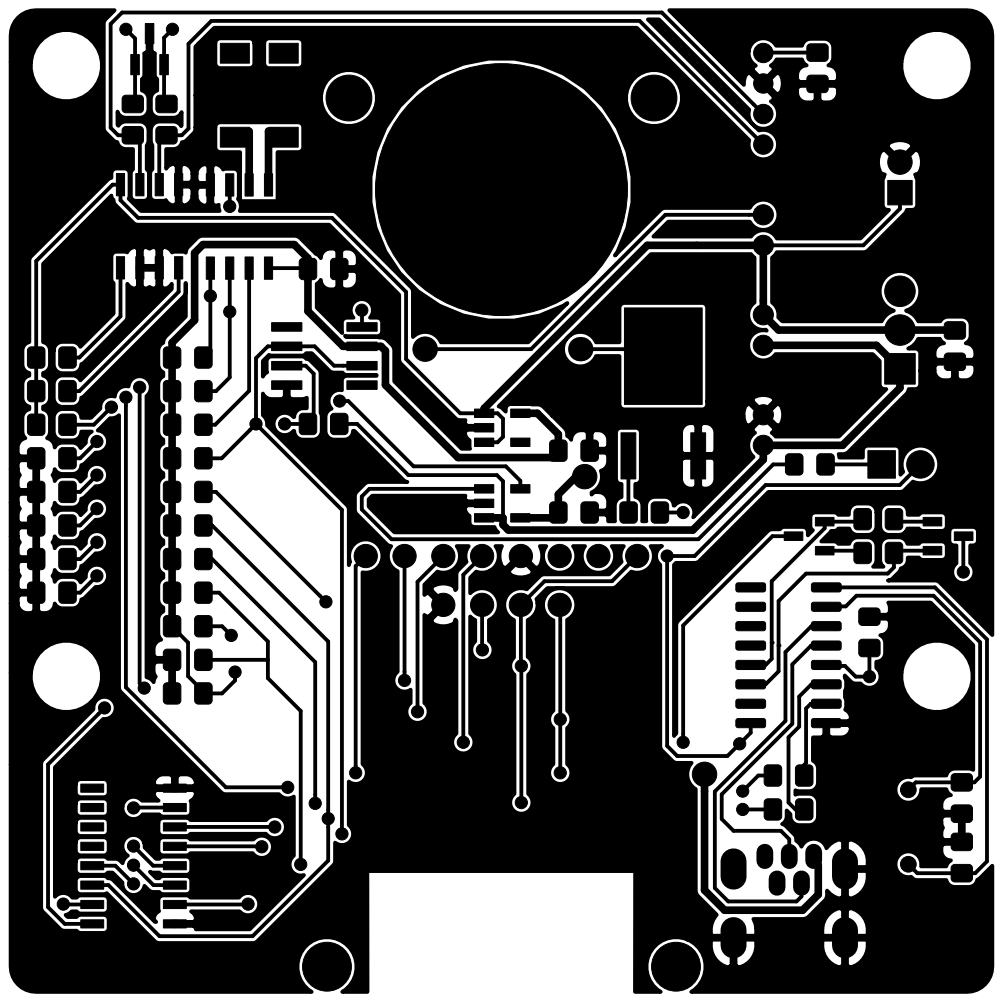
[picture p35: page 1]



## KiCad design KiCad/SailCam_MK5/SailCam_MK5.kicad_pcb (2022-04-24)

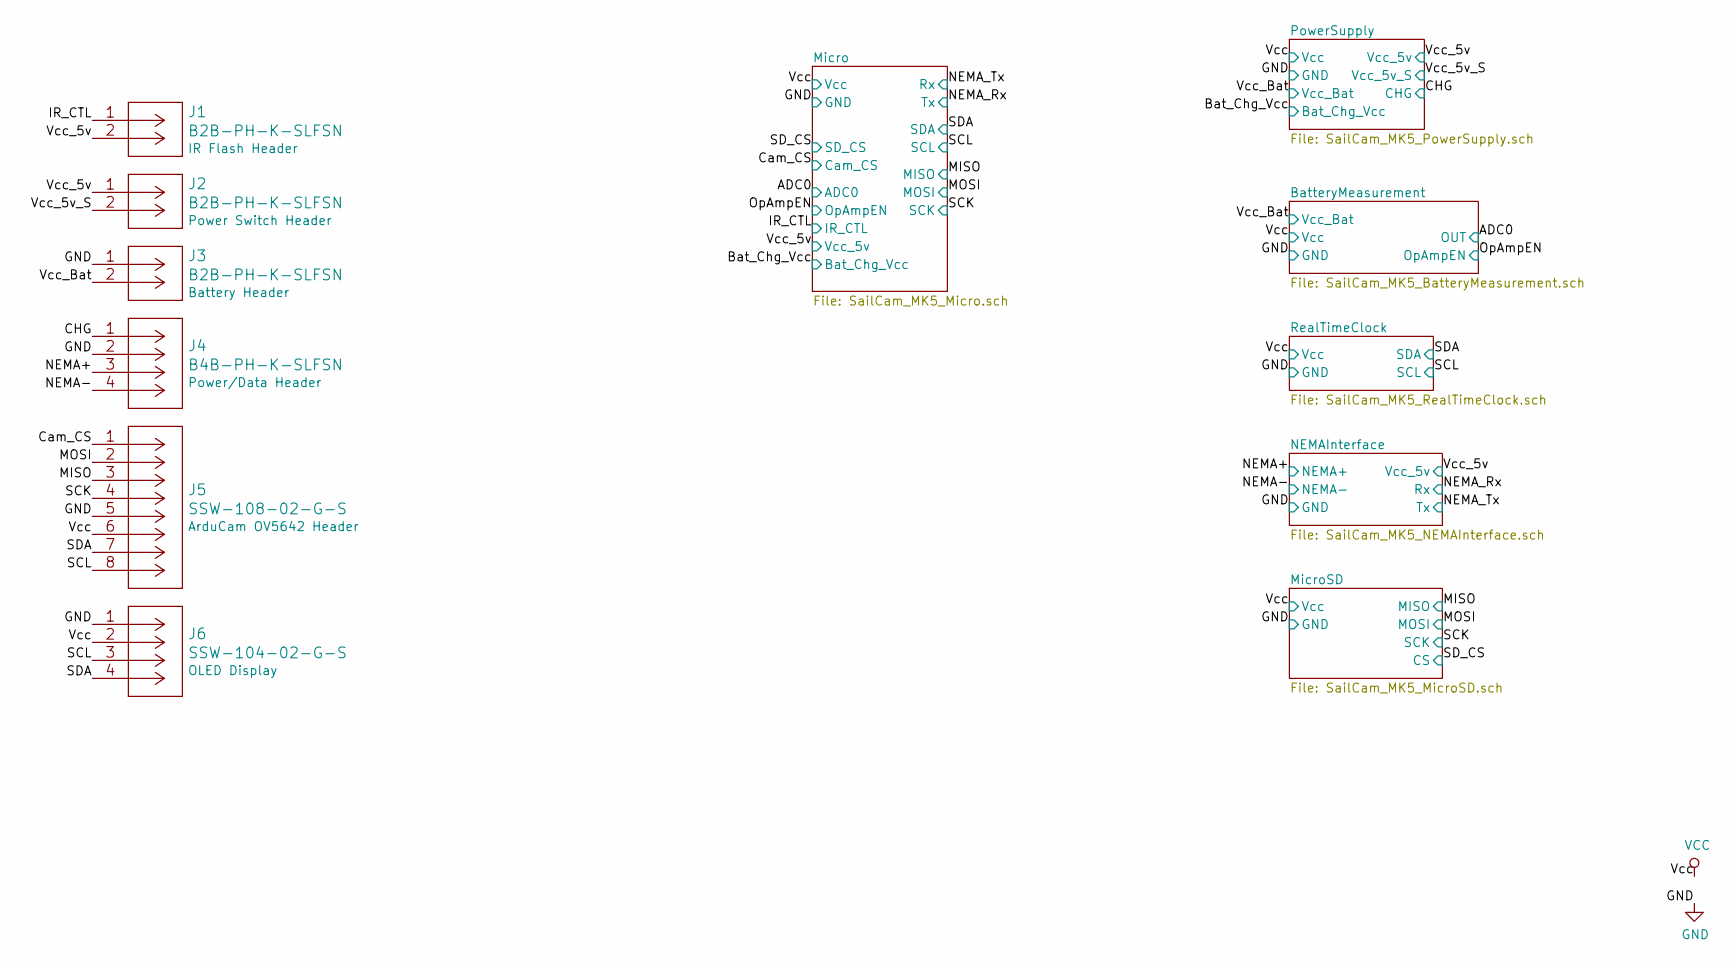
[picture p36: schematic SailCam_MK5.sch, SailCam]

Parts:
J1, J2, J3: B2B-PH-K-SLFSN
J4: B4B-PH-K-SLFSN
J5: SSW-108-02-G-S
J6: SSW-104-02-G-S; SSW-104-02-G-S_OLED

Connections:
/CHG: J4.1; also elsewhere on the board
/Cam_CS: J5.1; also elsewhere on the board
/IR_CTL: J1.1; also elsewhere on the board
/MISO: J5.3; also elsewhere on the board
/MOSI: J5.2; also elsewhere on the board
/NEMA+: J4.3; also elsewhere on the board
/NEMA-: J4.4; also elsewhere on the board
/SCK: J5.4; also elsewhere on the board
/SCL: J5.8, J6.3; also elsewhere on the board
/SDA: J5.7, J6.4; also elsewhere on the board
/Vcc_5v: J1.2, J2.1; also elsewhere on the board
/Vcc_5v_S: J2.2, J3.2; also elsewhere on the board
GND: J3.1, J4.2, J5.5, J6.1; also elsewhere on the board
VCC: J5.6, J6.2; also elsewhere on the board

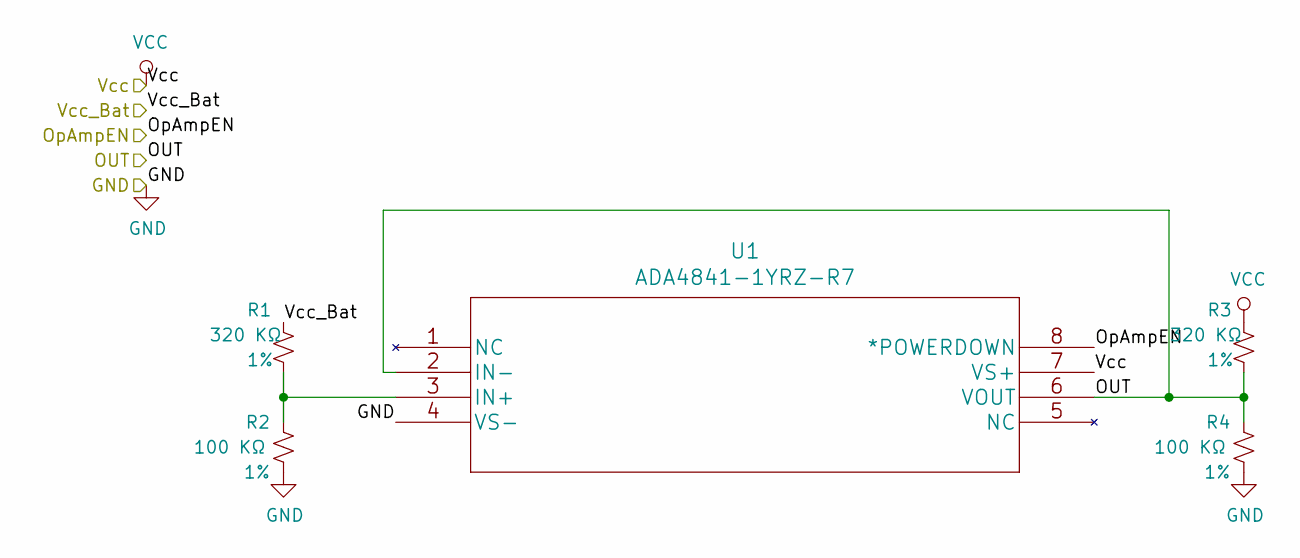
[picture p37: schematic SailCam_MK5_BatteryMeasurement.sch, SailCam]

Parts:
R1, R3: 320 KΩ; C_0805_2012Metric_Pad1.15x1.40mm_HandSolder_FullSilk; Tolerance 1%
R2, R4: 100 KΩ; C_0805_2012Metric_Pad1.15x1.40mm_HandSolder_FullSilk; Tolerance 1%
U1: ADA4841-1YRZ-R7

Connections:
/ADC0: R3.2, R4.2, U1.2 (IN-), U1.6 (VOUT); also elsewhere on the board
/OpAmpEN: U1.8 (*POWERDOWN); also elsewhere on the board
/Vcc_5v_S: R1.1; also elsewhere on the board
GND: R2.1, R4.1, U1.4 (VS-); also elsewhere on the board
unnamed: R1.2, R2.2, U1.3 (IN+)
VCC: R3.1, U1.7 (VS+); also elsewhere on the board

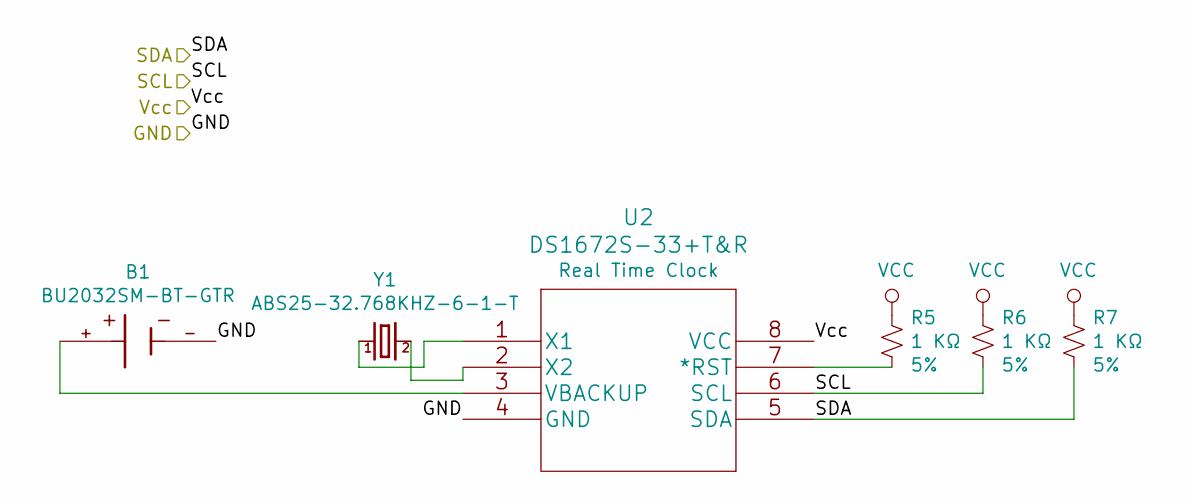
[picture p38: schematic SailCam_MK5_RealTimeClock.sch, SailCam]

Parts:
B1: BU2032SM-BT-GTR; BAT_BU2032SM-BT-GTR; PARTREV F
R5, R6, R7: 1 KΩ; C_0805_2012Metric_Pad1.15x1.40mm_HandSolder_FullSilk; Tolerance 5%
U2: DS1672S-33+T&R; DS1672S-33&plus_T&R
Y1: ABS25-32.768KHZ-6-1-T; XTAL_ABS25-32.768KHZ-6-1-T

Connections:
/SCL: R6.2, U2.6 (SCL); also elsewhere on the board
/SDA: R7.2, U2.5 (SDA); also elsewhere on the board
GND: B1.-, U2.4 (GND); also elsewhere on the board
unnamed: B1.+, U2.3 (VBACKUP)
unnamed: R5.2, U2.7 (*RST)
unnamed: U2.1 (X1), Y1.1
unnamed: U2.2 (X2), Y1.4
VCC: R5.1, R6.1, R7.1, U2.8 (VCC); also elsewhere on the board

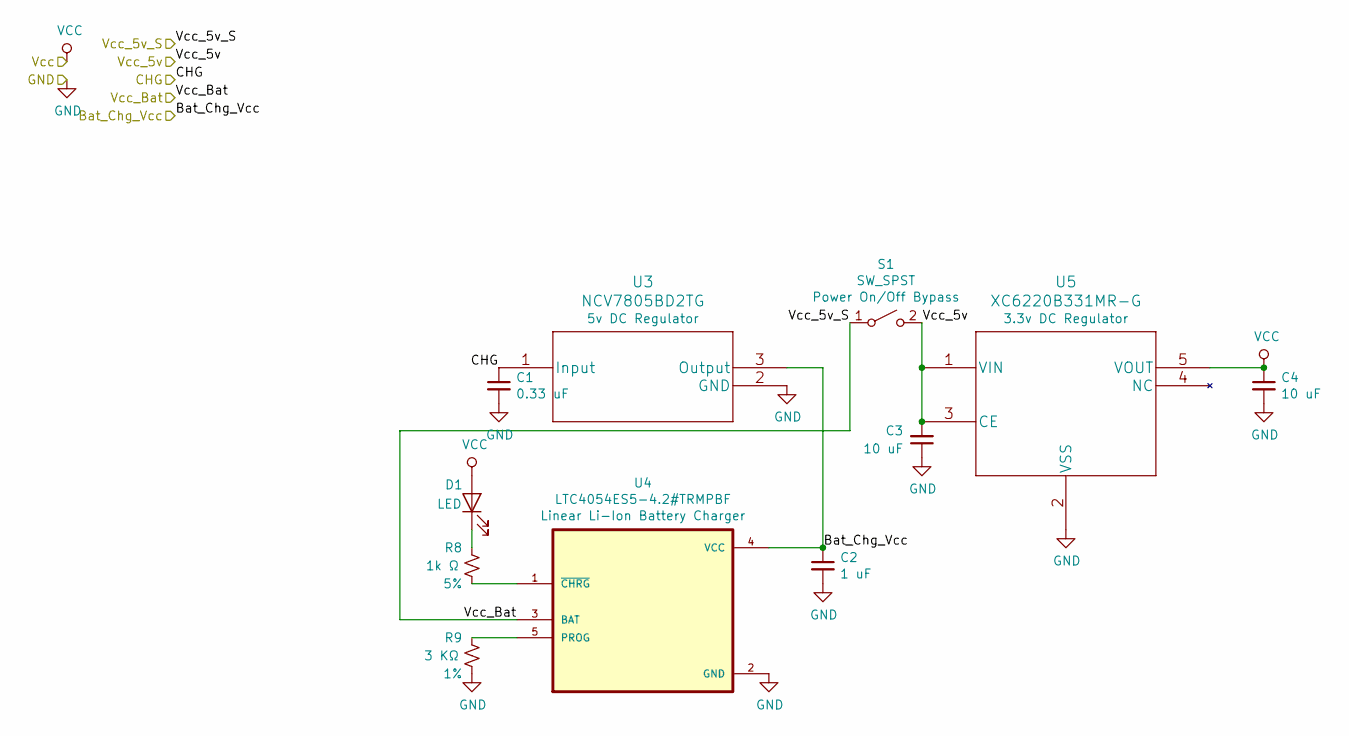
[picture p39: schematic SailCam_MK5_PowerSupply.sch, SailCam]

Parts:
C1: 0.33 uF; C_0805_2012Metric_Pad1.15x1.40mm_HandSolder_FullSilk
C2: 1 uF; C_0805_2012Metric_Pad1.15x1.40mm_HandSolder_FullSilk
C3, C4: 10 uF; C_0805_2012Metric_Pad1.15x1.40mm_HandSolder_FullSilk
D1: LED; LED_D3.0mm
R8: 1k Ω; C_0805_2012Metric_Pad1.15x1.40mm_HandSolder_FullSilk; Tolerance 5%
R9: 3 KΩ; C_0805_2012Metric_Pad1.15x1.40mm_HandSolder_FullSilk; Tolerance 1%
S1: SW_SPST; Switch_Toggle_ATE1D-2M3-10-Z
U3: NCV7805BD2TG
U4: LTC4054ES5-4.2#TRMPBF; SOT95P280X100-5N
U5: XC6220B331MR-G

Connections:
/Bat_Chg_Vcc: C2.1, U3.3 (Output), U4.4 (VCC); also elsewhere on the board
/CHG: C1.1, U3.1 (Input); also elsewhere on the board
/Vcc_5v: C3.2, S1.2 (B), U5.1 (VIN), U5.3 (CE); also elsewhere on the board
/Vcc_5v_S: S1.1 (A), U4.3 (BAT); also elsewhere on the board
GND: C1.2, C2.2, C3.1, C4.2, R9.1, U3.2 (GND), U4.2 (GND), U5.2 (VSS); also elsewhere on the board
unnamed: D1.1 (K), R8.2
unnamed: R8.1, U4.1 (~CHRG)
unnamed: R9.2, U4.5 (PROG)
VCC: C4.1, D1.2 (A), U5.5 (VOUT); also elsewhere on the board

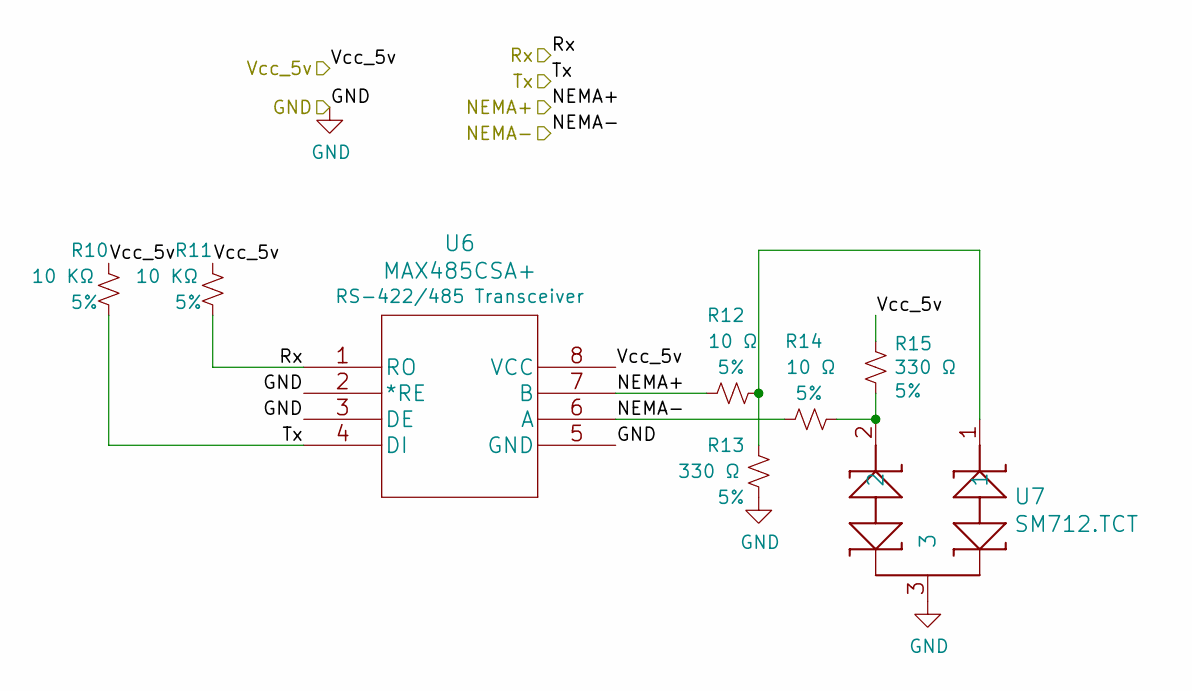
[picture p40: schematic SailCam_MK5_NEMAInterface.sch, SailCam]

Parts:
R10, R11: 10 KΩ; C_0805_2012Metric_Pad1.15x1.40mm_HandSolder_FullSilk; Tolerance 5%
R12, R14: 10 Ω; C_0805_2012Metric_Pad1.15x1.40mm_HandSolder_FullSilk; Tolerance 5%
R13, R15: 330 Ω; C_0805_2012Metric_Pad1.15x1.40mm_HandSolder_FullSilk; Tolerance 5%
U6: MAX485CSA+; MAX485CSA&plus_
U7: SM712.TCT

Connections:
/NEMA+: R12.1, U6.7 (B); also elsewhere on the board
/NEMA-: R14.1, U6.6 (A); also elsewhere on the board
/NEMA_Rx: R11.2, U6.1 (RO)
/NEMA_Tx: R10.2, U6.4 (DI)
/Vcc_5v: R10.1, R11.1, R15.1, U6.8 (VCC); also elsewhere on the board
GND: R13.1, U6.2 (*RE), U6.3 (DE), U6.5 (GND), U7.3; also elsewhere on the board
unnamed: R12.2, R13.2, U7.1
unnamed: R14.2, R15.2, U7.2

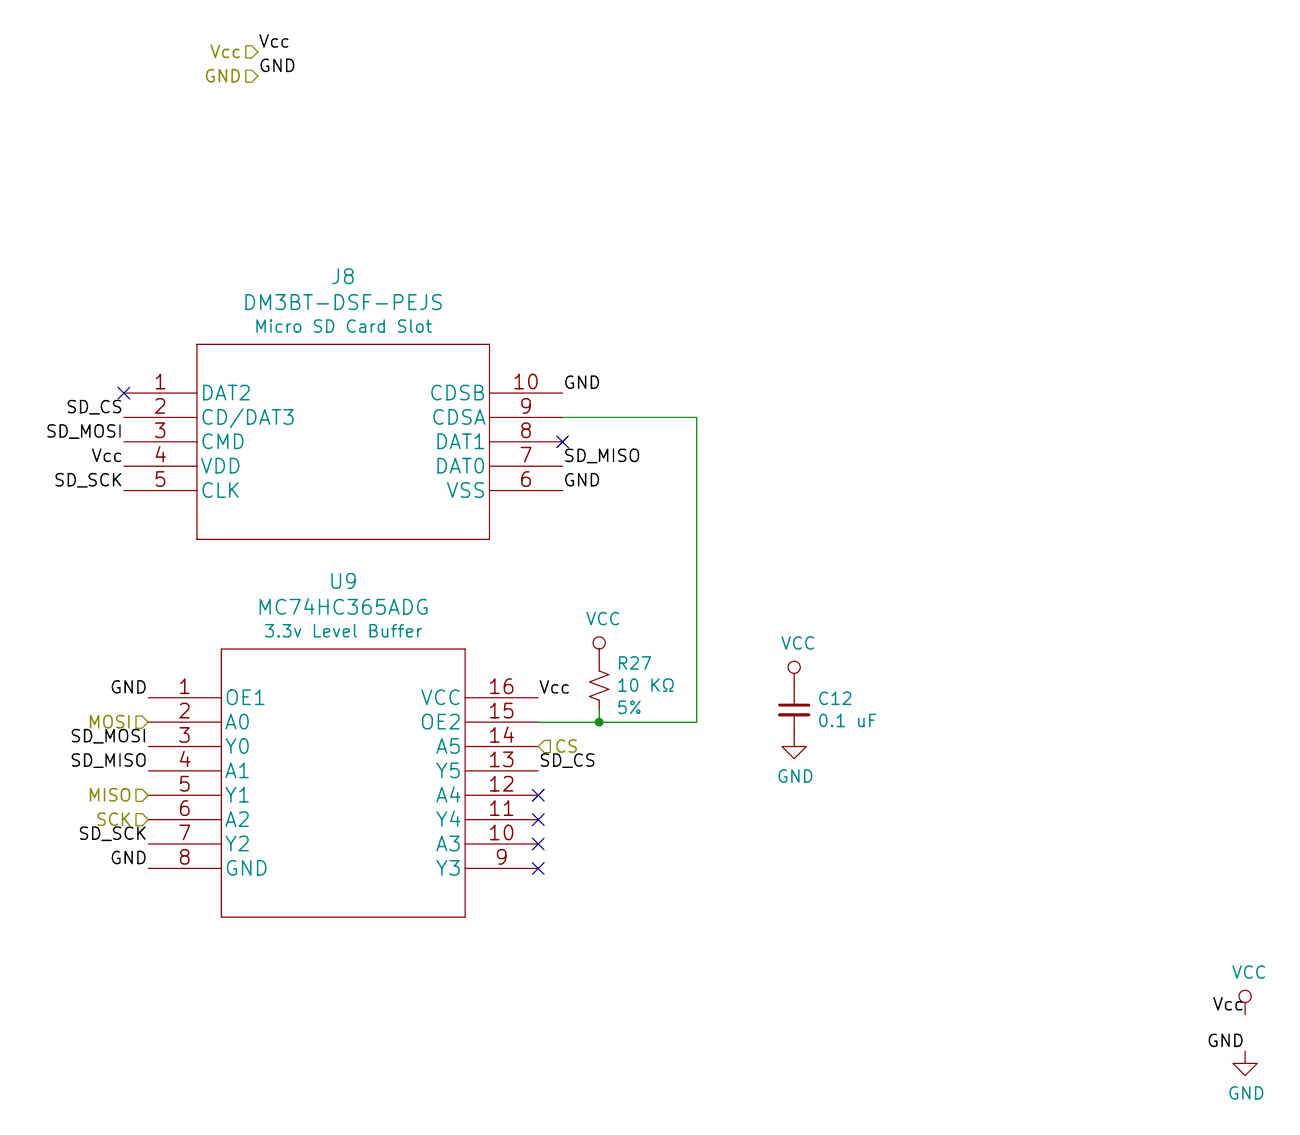
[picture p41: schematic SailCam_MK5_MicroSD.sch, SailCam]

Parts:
C12: 0.1 uF; C_0805_2012Metric_Pad1.15x1.40mm_HandSolder_FullSilk
J8: DM3BT-DSF-PEJS
R27: 10 KΩ; C_0805_2012Metric_Pad1.15x1.40mm_HandSolder_FullSilk; Tolerance 5%
U9: MC74HC365ADG

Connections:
/MISO: U9.5 (Y1); also elsewhere on the board
/MOSI: U9.2 (A0); also elsewhere on the board
/MicroSD/SD_CS: J8.2 (CD/DAT3), U9.13 (Y5)
/MicroSD/SD_MISO: J8.7 (DAT0), U9.4 (A1)
/MicroSD/SD_MOSI: J8.3 (CMD), U9.3 (Y0)
/MicroSD/SD_SCK: J8.5 (CLK), U9.7 (Y2)
/SCK: U9.6 (A2); also elsewhere on the board
/SD_CS: U9.14 (A5); also elsewhere on the board
GND: C12.2, J8.6 (VSS), J8.10 (CDSB), U9.1 (OE1), U9.8 (GND); also elsewhere on the board
unnamed: J8.9 (CDSA), R27.2, U9.15 (OE2)
VCC: C12.1, J8.4 (VDD), R27.1, U9.16 (VCC); also elsewhere on the board

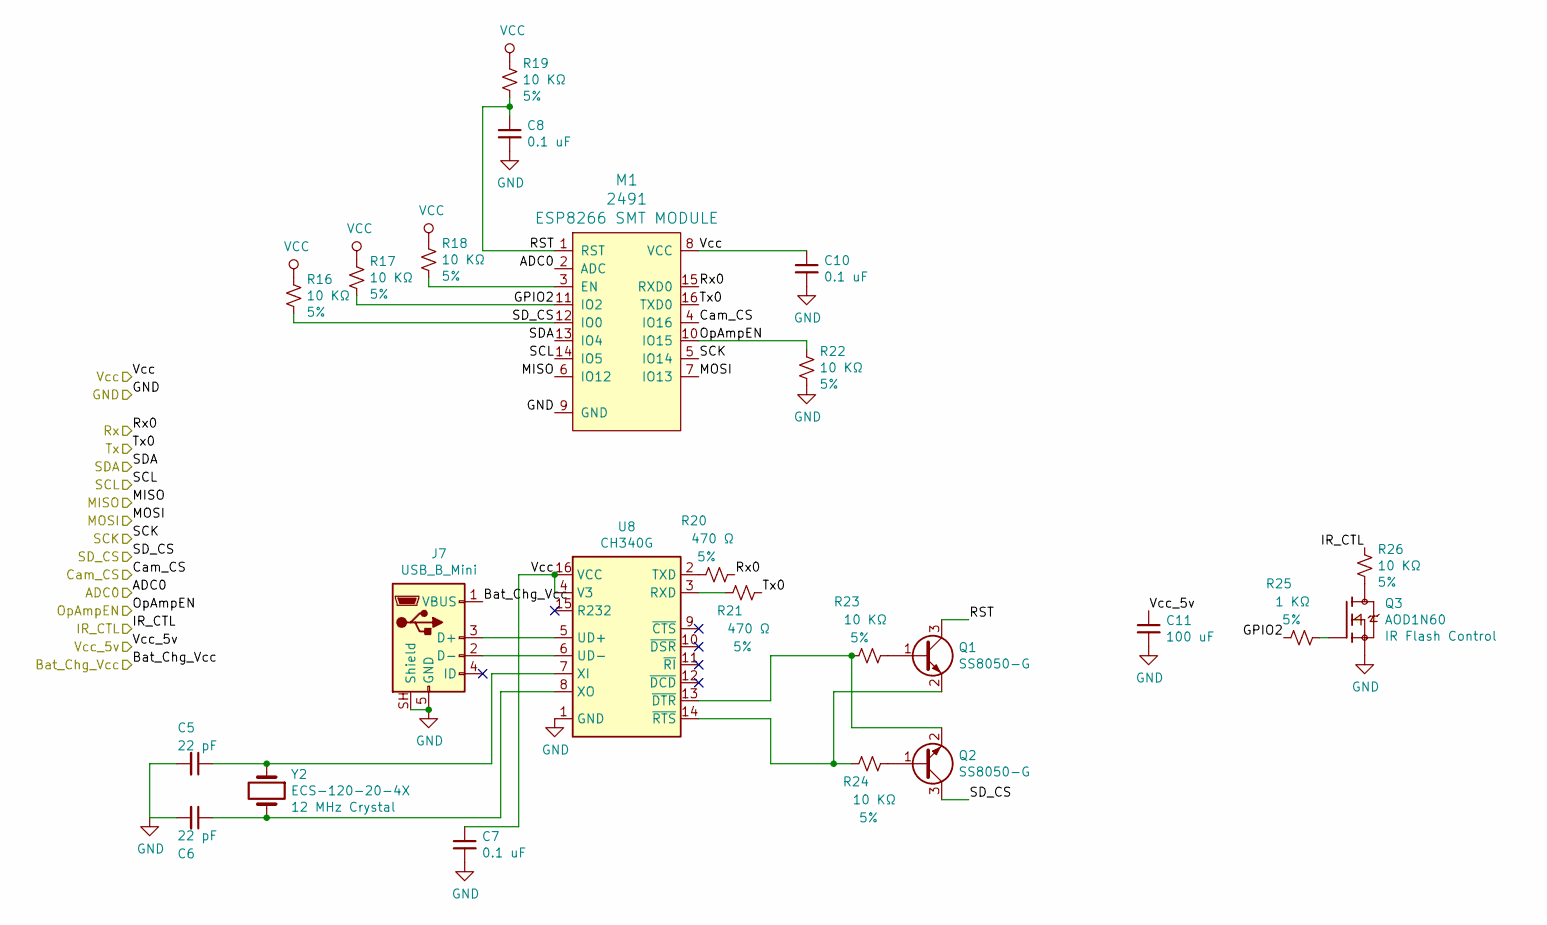
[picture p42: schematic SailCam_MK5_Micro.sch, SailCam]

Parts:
C5, C6: 22 pF; C_0805_2012Metric_Pad1.15x1.40mm_HandSolder_FullSilk
C7, C8, C10: 0.1 uF; C_0805_2012Metric_Pad1.15x1.40mm_HandSolder_FullSilk
C11: 100 uF; CP_Radial_D5.0mm_P2.00mm
J7: USB_B_Mini; USB_Mini_B_Female_548190519
M1: 2491; WIFI_Module_ESP8266_2491; MPN 2491; Digi-Key_PN 1528-1438-ND
Q1, Q2: SS8050-G
Q3: AOD1N60; TO228P1003X240-3N; PARTREV U
R16, R17, R18, R19, R22, R23, R24: 10 KΩ; C_0805_2012Metric_Pad1.15x1.40mm_HandSolder_FullSilk; Tolerance 5%
R20, R21: 470 Ω; C_0805_2012Metric_Pad1.15x1.40mm_HandSolder_FullSilk; Tolerance 5%
R25: 1 KΩ; C_0805_2012Metric_Pad1.15x1.40mm_HandSolder_FullSilk; Tolerance 5%
R26: 10 KΩ; R_Box_L8.4mm_W2.5mm_P5.08mm; Tolerance 5%
U8: CH340G; SOIC-16_3.9x9.9mm_P1.27mm
Y2: ECS-120-20-4X; XTAL_ECS-120-20-4X

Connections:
/ADC0: M1.2 (ADC); also elsewhere on the board
/Bat_Chg_Vcc: J7.1 (VBUS); also elsewhere on the board
/Cam_CS: M1.4 (IO16); also elsewhere on the board
/IR_CTL: R26.1; also elsewhere on the board
/MISO: M1.6 (IO12); also elsewhere on the board
/MOSI: M1.7 (IO13); also elsewhere on the board
/Micro/GPIO2: M1.11 (IO2), R17.2, R25.1
/Micro/RST: C8.1, M1.1 (RST), Q1.3 (C), R19.2
/Micro/Rx0: M1.15 (RXD0), R20.2
/Micro/Tx0: M1.16 (TXD0), R21.2
/OpAmpEN: M1.10 (IO15), R22.1; also elsewhere on the board
/SCK: M1.5 (IO14); also elsewhere on the board
/SCL: M1.14 (IO5); also elsewhere on the board
/SDA: M1.13 (IO4); also elsewhere on the board
/SD_CS: M1.12 (IO0), Q2.3 (C), R16.2; also elsewhere on the board
/Vcc_5v: C11.1; also elsewhere on the board
GND: C5.2, C6.2, C7.2, C8.2, C10.2, C11.2, J7.5 (GND), J7.SH (Shield), M1.9 (GND), Q3.3, R22.2, U8.1 (GND); also elsewhere on the board
unnamed: C5.1, U8.7 (XI), Y2.1
unnamed: C6.1, U8.8 (XO), Y2.2
unnamed: J7.2 (D-), U8.6 (UD-)
unnamed: J7.3 (D+), U8.5 (UD+)
unnamed: M1.3 (EN), R18.2
unnamed: Q1.1 (B), R23.2
unnamed: Q1.2 (E), R24.1, U8.14 (~RTS)
unnamed: Q2.1 (B), R24.2
unnamed: Q2.2 (E), R23.1, U8.13 (~DTR)
unnamed: Q3.1, R25.2
unnamed: Q3.4, R26.2
unnamed: R20.1, U8.2 (TXD)
unnamed: R21.1, U8.3 (RXD)
VCC: C7.1, C10.1, M1.8 (VCC), R16.1, R17.1, R18.1, R19.1, U8.4 (V3), U8.16 (VCC); also elsewhere on the board

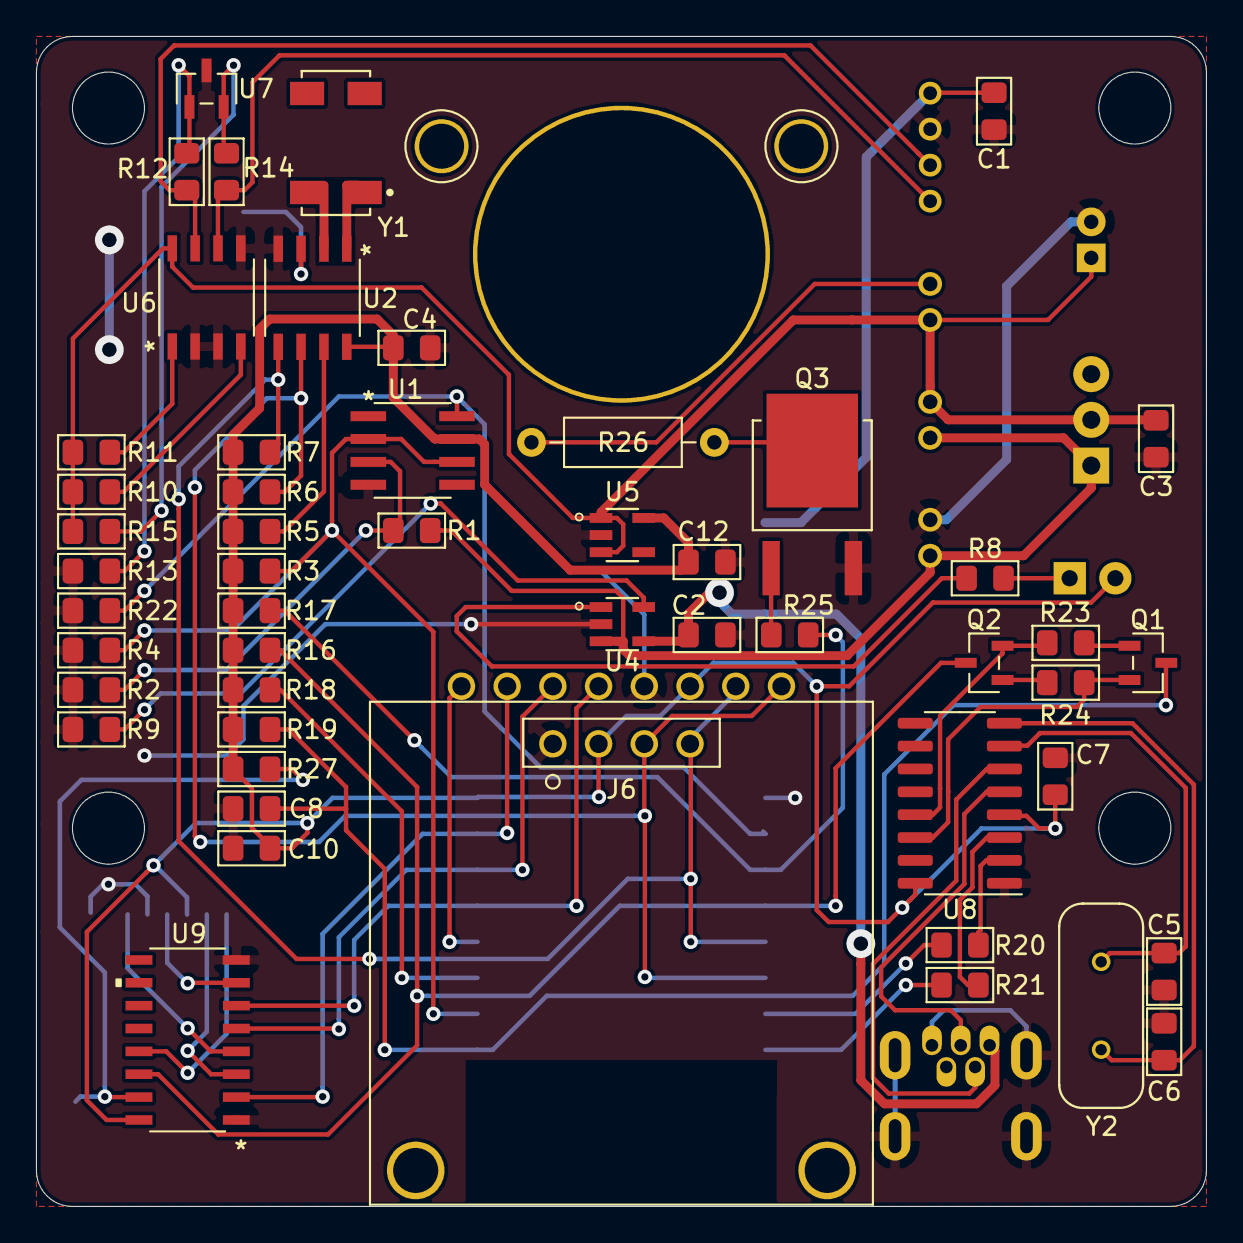
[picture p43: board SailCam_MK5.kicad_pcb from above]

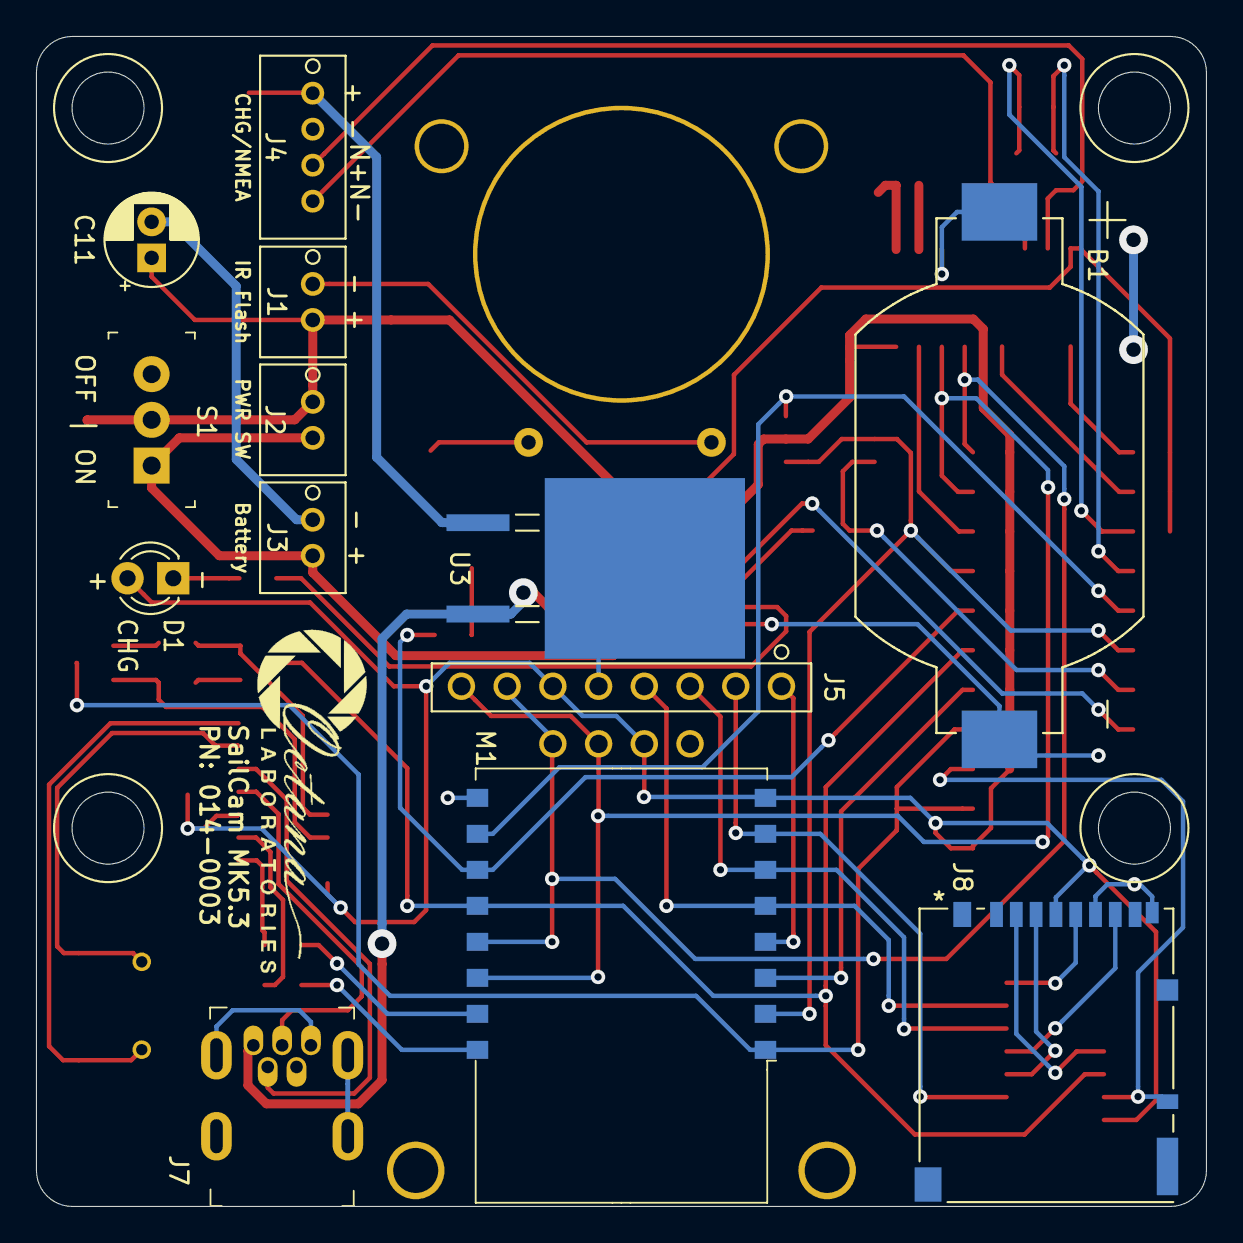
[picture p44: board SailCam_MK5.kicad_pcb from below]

Board: 2 copper layers, 65.0 x 65.0 mm, 64 parts (13 on the bottom side), 52 nets.

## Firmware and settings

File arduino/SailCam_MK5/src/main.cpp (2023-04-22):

/*
  Author: Tyler Thompson
  Date: Aug 21, 2021
  Description: SailCam MK5 Firmware
*/

#include <Arduino.h>
#include <hardware/drivers.h>
#include <web_server.h>
#include <settings/system_configuration.h>
#include <util/command_parser.h>

/* Function Prototypes */
bool is_capture_required();

char *stack_start;
// uint32_t loop_counter = 0;
uint32_t last_sys_time = 0;
uint32_t now_sys_time = 0;
char file_name[25];

WebServer* web_server;
CommandParser* command_parser;

DateTime* timestamp;

HardwareDrivers* hardware_drivers;

CameraState last_cam_state = SENSOR_POWER_DOWN;
bool cam_capture_required = false;

void setup() 
{
    char stack;
    stack_start = &stack;

    hardware_drivers = new HardwareDrivers();

    // initialize LED
    hardware_drivers->status_led = new StatusLED();

    // initalize serial terminal
    hardware_drivers->serial_term = new SerialTerminal(initial_hardware_serial_baud_rate);
    hardware_drivers->serial_term->debug_printf("Initial Baud: %d\r\n", initial_hardware_serial_baud_rate);

    // initialize OLED display
    hardware_drivers->old_display = new OledDisplay();

    // initialize RTC
    timestamp = new DateTime();
    hardware_drivers->system_clock = new Clock();
    *timestamp = hardware_drivers->system_clock->get_time();

    // initalize battery measurement device
    hardware_drivers->battery_management = new BatteryManagement();

    // initialize SD card and read config.ini
    hardware_drivers->storage_controller = new Storage(timestamp);
    hardware_drivers->storage_controller->log_data_point(*timestamp, (char *) "Booting up...");
    hardware_drivers->storage_controller->read_settings_file(hardware_drivers->serial_term);
    hardware_drivers->serial_term->debug_printf("New Baud will be: %d\r\n", hardware_drivers->storage_controller->get_system_configuration()->get_setting("baud_rate")->get_value_int());
    hardware_drivers->serial_term->reinitialize
    (
        hardware_drivers->storage_controller->get_system_configuration()->get_setting("baud_rate")->get_value_int()
    );
    hardware_drivers->storage_controller->print_configuration(hardware_drivers->serial_term);

    hardware_drivers->old_display->writef("SD Card: %s", hardware_drivers->storage_controller->is_card_connected() ? "True" : "False");
    hardware_drivers->old_display->update();
    hardware_drivers->old_display->set_sleep_time(hardware_drivers->storage_controller->get_system_configuration()->get_setting("display_sleep_time")->get_value_int());
    
    // write timestamp
    hardware_drivers->serial_term->debug_printf("System Time: %s\r\n", hardware_drivers->storage_controller->get_formatted_timestamp());
    hardware_drivers->old_display->write(hardware_drivers->storage_controller->get_formatted_timestamp());
    hardware_drivers->old_display->update();

    // initalize wifi
    hardware_drivers->wifi_radio = new Wifi
    (
        hardware_drivers->storage_controller->get_system_configuration()->get_setting("wifi_ssid")->get_value_str(),
        hardware_drivers->storage_controller->get_system_configuration()->get_setting("wifi_psk")->get_value_str(),
        hardware_drivers->storage_controller->get_system_configuration()->get_setting("tcp_port")->get_value_int(),
        (WIFI_MODE) hardware_drivers->storage_controller->get_system_configuration()->get_setting("wifi_mode")->get_value_int(),
        (TCP_SERVER_MODE) hardware_drivers->storage_controller->get_system_configuration()->get_setting("tcp_mode")->get_value_int()
    );

    // initalize camera
    hardware_drivers->camera = new Camera(hardware_drivers->storage_controller);
    char* cam_self_test = (char*) malloc(50);
    hardware_drivers->old_display->writef("CAM: %s", hardware_drivers->camera->run_self_test(&cam_self_test) ? "True" : "False");
    hardware_drivers->old_display->update();
    hardware_drivers->serial_term->debug_printf("%s\r\n", cam_self_test);
    hardware_drivers->storage_controller->log_data_point(*timestamp, cam_self_test);
    free(cam_self_test);

    // initialize API command parser
    command_parser = new CommandParser(hardware_drivers, stack_start);

    // initalize web server
    web_server = new WebServer(hardware_drivers, command_parser);

    // If in wifi client mode, wait for wifi to connect. Blink led based on successful/unsuccessful connection
    if (hardware_drivers->wifi_radio->get_wifi_mode() == WIFI_CLIENT) {
        int timeout = 0;
        hardware_drivers->serial_term->debug_print("Connecting to WiFi...");
        hardware_drivers->old_display->write("Connecting to WiFi...");
        hardware_drivers->old_display->update();
        while (hardware_drivers->wifi_radio->get_connection_status() != WL_CONNECTED && timeout < wifi_client_connect_timeout) {
            delay(500);
            timeout += 500;
            hardware_drivers->serial_term->debug_print(".");
        }
        if (hardware_drivers->wifi_radio->get_connection_status() == WL_CONNECTED) {
            hardware_drivers->status_led->info();
            hardware_drivers->serial_term->debug_println(" WiFi Connected.");
            hardware_drivers->old_display->write("WiFi Connected.");
            hardware_drivers->old_display->update();
        } else {
            hardware_drivers->status_led->error();
            hardware_drivers->serial_term->debug_println(" WiFi Failed to Connect.");
            hardware_drivers->old_display->write("WiFi Failed to Connect.");
            hardware_drivers->old_display->update();
            hardware_drivers->storage_controller->log_data_point(*timestamp, (char*) "Timeout reached connecting to wifi.");
        }
    }

    hardware_drivers->old_display->write(hardware_drivers->wifi_radio->get_ip_address().toString().c_str());
    hardware_drivers->old_display->update();

    // boot complete
    hardware_drivers->storage_controller->log_data_point(*timestamp, (char *) "Boot complete!");
    hardware_drivers->serial_term->debug_println("Boot Complete!");
    hardware_drivers->old_display->write("Boot Complete!");
    hardware_drivers->old_display->update();
    hardware_drivers->status_led->blink(2, 250);
}  // end setup()

void loop() 
{
    *timestamp = hardware_drivers->system_clock->get_time();

    // run auto capture
    if ((hardware_drivers->storage_controller->get_system_configuration()->get_setting("capture_mode")->get_value_int() == 1) && (is_capture_required())) {
        hardware_drivers->camera->capture_image(*timestamp);
    }

    // process the camera
    hardware_drivers->camera->process();
    if (hardware_drivers->camera->get_state() != last_cam_state)
    {
        // print timestamp
        hardware_drivers->serial_term->debug_printf
        (
            "System Time: %02d/%02d/%04d %02d:%02d:%02d\r\n", 
            timestamp->month(),
            timestamp->day(),  
            timestamp->year(), 
            timestamp->hour(), 
            timestamp->minute(), 
            timestamp->second()
        );

        // print camera state
        hardware_drivers->serial_term->debug_printf("Camera State: %d\r\n", hardware_drivers->camera->get_state());
        if (hardware_drivers->camera->get_state() == SENSOR_POWER_DOWN) // if camera just entered power down, increment capture_count
        {
            hardware_drivers->storage_controller->increment_counter((char*) "capture_count", true);
            hardware_drivers->serial_term->debug_printf("%s\r\n", hardware_drivers->camera->get_last_save_file_name());
            cam_capture_required = false;
        }
        else if (hardware_drivers->camera->get_state() == ERROR_HANDLE) // if camera enters error state, log error
        {
            hardware_drivers->storage_controller->increment_counter((char*) "error_count", true);
            hardware_drivers->serial_term->debug_printf("CAMERA ERROR!!\r\n");
            hardware_drivers->storage_controller->log_data_point(*timestamp, (char *) "Camera error! ", true);
            hardware_drivers->storage_controller->log_error_code(hardware_drivers->camera->get_error_reason());
            hardware_drivers->old_display->wake_up();
        }
        
        last_cam_state = hardware_drivers->camera->get_state();
    }
    
    now_sys_time = system_get_time();
    if ((now_sys_time - last_sys_time) > 500000) { // run every ~500ms

        // update oled display
        hardware_drivers->old_display->set_mode((DisplayMode) hardware_drivers->storage_controller->get_system_configuration()->get_setting("display_mode")->get_value_int());
        hardware_drivers->old_display->write_overview(
            *timestamp, 
            hardware_drivers->wifi_radio->get_ip_address(), 
            hardware_drivers->storage_controller->get_system_configuration()->get_setting("wifi_mode")->get_value_int(),
            hardware_drivers->storage_controller->get_system_configuration()->get_setting("capture_count")->get_value_int(),
            hardware_drivers->storage_controller->get_system_configuration()->get_setting("capture_mode")->get_value_int(),
            hardware_drivers->storage_controller->get_system_configuration()->get_setting("capture_interval")->get_value_int(),
            hardware_drivers->storage_controller->get_system_configuration()->get_setting("error_count")->get_value_int(),
            hardware_drivers->battery_management->get_battery_volts());
        hardware_drivers->old_display->update();

        // set dim base on hour
        hardware_drivers->old_display->dim((timestamp->hour() > dim_begin_hour) || (timestamp->hour() < dim_end_hour));

        last_sys_time = now_sys_time;
    }
    
    // handle wifi interfaces
    if (hardware_drivers->wifi_radio->get_wifi_mode() != WIFI_DISABLED) {
        // handle web server clients
        web_server->handle_client();

        // process API data on the TCP port
        if (hardware_drivers->wifi_radio->get_tcp_mode() == TCP_SERVER_ENABLED)
        {
            hardware_drivers->wifi_radio->read_server_data();
            if (hardware_drivers->wifi_radio->new_data_available()) {
                command_parser->process_tcp_api();
            }
        }
    }

    // read data from the serial terminal, process API commands if needed
    hardware_drivers->serial_term->read_data();
    if (hardware_drivers->serial_term->new_data_available()) {
        hardware_drivers->serial_term->debug_printf(">%s\r\n", hardware_drivers->serial_term->get_data());
        command_parser->process_serial_terminal();
    }

    /* reboot if requested */
    if (hardware_drivers->camera->is_reboot_requested() || 
        command_parser->is_reboot_requested())
    {
        hardware_drivers->storage_controller->log_data_point(*timestamp, (char*)"Reboot requested!");
        ESP.restart();
    }

    yield();
}  // end loop()

bool is_capture_required()
{
    if ((cam_capture_required == false) && 
        (timestamp->secondstime() % (uint32_t)hardware_drivers->storage_controller->get_system_configuration()->get_setting("capture_interval")->get_value_int() == 0)) 
    {
        hardware_drivers->serial_term->debug_printf("CAPTURE REQUIRED\r\n");
        cam_capture_required = true;
        return true;
    } 
    else 
    {
        return false;
    }
}

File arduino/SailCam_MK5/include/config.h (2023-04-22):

#define firmware_version "MK 5.2"

#define sd_card_chip_select 0
#define camera_chip_select 16

#define status_led_pin 2

#define battery_measure_adc_channel A0
#define battery_measure_op_disable_pin 15
#define battery_measure_adc_resolution 1024
#define battery_max_volts 4.3
#define battery_min_volts 2.5

#define serial_buffer_length 1024 // max length of stored messages
#define serial_min_read 1 // minimum number of characters that need to appear in a message for it to register
#define command_message_buffer_length 8192
#define file_buffer_size 50

#define ap_local_ip 192,168,22,2
#define ap_gateway_address 192,168,22,1
#define ap_subnet_mask 255,255,255,0

#define wifi_client_connect_timeout 30000

#define web_server_port 80

#define log_folder_base_dir "logs"
#define log_folder_base_dir_length 4

#define image_base_dir "images"

#define system_configuration_path "config.ini"
#define camera_settings_path "camera_config.ini"
#define root_html_file "/api?command=cat&arg=/html/controls.html"

#define hardware_serial_port UART0
#define initial_hardware_serial_baud_rate 9600

#define serial_debug_messages false

#define min_heap_size 6128
#define total_stack_size 4048
#define max_buffer_size 10000

#define boot_message "\r\n   _____       _ _  _____                 "\
                     "\r\n  / ____|     (_) |/ ____|                "\
                     "\r\n | (___   __ _ _| | |     __ _ _ __ ___   "\
                     "\r\n  \\___ \\ / _` | | | |    / _` | '_ ` _ \\  "\
                     "\r\n  ____) | (_| | | | |___| (_| | | | | | | "\
                     "\r\n |_____/ \\__,_|_|_|\\_____\\__,_|_| |_| |_| \r\n"

#define oled_boot_message "\n _ _ o|  _ _  _ _\n"\
                          "_\\(_||| (_(_|| | |"
                          
#define oled_capture_message "          _\n"\
                             "        _|#|_\n"\
                             "       | (O) |\n"\
                             "        -----\n"

/**
 * IO Pinout
 * 0    SD CS
 * 2    IR/Status LED
 * 4    SDA
 * 5    SCL
 * 12   MISO
 * 13   MOSI
 * 14   SCK
 * 15   OpAmpEN
 * 16   CAM CS
 */

/**
 * I2C Slave Addresses
 * 0x3D - OLED Display
 * 0x78 - Camera
 * 0x68 - RTC
 */

/*

//Light Mode
#define Advanced_AWB         0
#define Simple_AWB           1
#define Manual_day           2
#define Manual_A             3
#define Manual_cwf           4
#define Manual_cloudy        5

//Color Saturation 
#define Saturation4          0
#define Saturation3          1
#define Saturation2          2
#define Saturation1          3
#define Saturation0          4
#define Saturation_1         5
#define Saturation_2         6
#define Saturation_3         7
#define Saturation_4         8

//Brightness
#define Brightness4          0
#define Brightness3          1
#define Brightness2          2
#define Brightness1          3
#define Brightness0          4 *
#define Brightness_1         5
#define Brightness_2         6
#define Brightness_3         7
#define Brightness_4         8

//Contrast
#define Contrast4            0
#define Contrast3            1
#define Contrast2            2
#define Contrast1            3
#define Contrast0            4
#define Contrast_1           5
#define Contrast_2           6
#define Contrast_3           7
#define Contrast_4           8

//Special effects
#define Antique                      0
#define Bluish                       1
#define Greenish                     2
#define Reddish                      3
#define BW                           4
#define Negative                     5
#define BWnegative                   6
#define Normal                       7
#define Sepia                        8
#define Overexposure                 9
#define Solarize                     10
#define  Blueish                     11
#define Yellowish                    12

//Hue
#define degree_180            0
#define degree_150            1
#define degree_120            2
#define degree_90             3
#define degree_60             4
#define degree_30             5
#define degree_0              6
#define degree30              7
#define degree60              8
#define degree90              9
#define degree120             10
#define degree150             11

//Exposure
#define Exposure_17_EV                    0
#define Exposure_13_EV                    1
#define Exposure_10_EV                    2
#define Exposure_07_EV                    3
#define Exposure_03_EV                    4
#define Exposure_default                  5
#define Exposure03_EV                     6
#define Exposure07_EV                     7
#define Exposure10_EV                     8
#define Exposure13_EV                     9
#define Exposure17_EV                     10
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

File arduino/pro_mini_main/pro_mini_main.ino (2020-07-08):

/*
 * SailCam
 * @author: Tyler Thompson
 * @description: Arduino Mini Pro firmware used for interfacing an ArduCam OV5642 with a SD card. Use arduino IDE 1.6.8 or above.
 * @date: April 16, 2019
 */

#include <Wire.h>
#include <ArduCAM.h>
#include <SPI.h>
#include <SD.h>
#include "memorysaver.h"
#include <DS3231.h>

#if !defined (OV5642_MINI_5MP_PLUS)
  #error Please select the hardware platform and camera module in the ../libraries/ArduCAM/memorysaver.h file
#endif

#define FRAMES_NUM   0x00 // specifies number of pictures to take
#define CAM_CS       7
#define SD_CS        4
#define PWR_Relay    2
#define IR_Relay     3
#define led_pin      10
#define sleep_time   100
#define sunrise_hour 6
#define sunset_hour  21

DS3231 Clock;
RTClib RTC;
DateTime datetime;
File outFile;
ArduCAM myCAM(OV5642, CAM_CS);

bool is_header = false;
bool night_mode = false;
char filename[] = "0000/00/00/00_00_00.jpg";
char year_filename[] = "0000";
char month_filename[] = "0000/00";
char day_filename[] = "0000/00/00";


/*
 * Funtion Definitions
 */
void blink_led(int delay_time, int blink_times);
uint8_t read_fifo_burst(ArduCAM myCAM);
void set_night_mode(uint8_t Night_mode);


void setup() {
  uint8_t vid, pid;
  uint8_t temp;

  Wire.begin();
  
  Serial.begin(9600);
  Serial.println(F("MacCam Start!"));
  
  pinMode(CAM_CS, OUTPUT);
  pinMode(SD_CS, OUTPUT);
  pinMode(PWR_Relay, OUTPUT);
  pinMode(IR_Relay, OUTPUT);
  pinMode(led_pin, OUTPUT);
  digitalWrite(CAM_CS, HIGH);
  digitalWrite(SD_CS, HIGH);
  digitalWrite(PWR_Relay, LOW);
  digitalWrite(IR_Relay, LOW);
  digitalWrite(led_pin, LOW);

  Clock.setClockMode(false);  // set to 24h
  
  // initialize SPI:
  SPI.begin();
  //Reset the CPLD
  myCAM.write_reg(0x07, 0x80);
  delay(100);
  myCAM.write_reg(0x07, 0x00);
  delay(100); 

  while(1){
    //Check if the ArduCAM SPI bus is OK
    myCAM.write_reg(ARDUCHIP_TEST1, 0x55);
    temp = myCAM.read_reg(ARDUCHIP_TEST1);
    if(temp != 0x55)
    {
      Serial.println(F("SPI interface Error!"));
      blink_led(100, 1);
      delay(1000);
      continue;
    }else{
      Serial.println(F("SPI interface OK."));break;
    }
  }
  
  while(1){
    //Check if the camera module type is OV5642
    myCAM.rdSensorReg16_8(OV5642_CHIPID_HIGH, &vid);
    myCAM.rdSensorReg16_8(OV5642_CHIPID_LOW, &pid);
    if ((vid != 0x56) || (pid != 0x42)){
      Serial.println(F("Can't find OV5642 module!"));
      blink_led(100, 2);
      delay(1000);
      continue;
    }else{
      Serial.println(F("OV5642 detected."));break;      
    }
  }

  //Change to JPEG capture mode and initialize the OV5640 module
  myCAM.set_format(JPEG);
  myCAM.InitCAM();
  myCAM.set_bit(ARDUCHIP_TIM, VSYNC_LEVEL_MASK);
  myCAM.clear_fifo_flag();
  myCAM.write_reg(ARDUCHIP_FRAMES, FRAMES_NUM);
  //myCAM.set_bit(ARDUCHIP_GPIO,GPIO_PWDN_MASK);

  //Initialize SD Card
  while(!SD.begin(SD_CS))
  {
    Serial.println(F("SD Card Error!"));
    blink_led(100, 3);
    delay(1000);
  }
  Serial.println(F("SD Card detected."));

  blink_led(500,2);
  
}

void loop() {
  
//  uint8_t reg_val;
//  Serial.print("DEBUG: ");
//  myCAM.rdSensorReg16_8(0x3a17,&reg_val);
//  Serial.print("Gain Base: ");
//  Serial.print(reg_val, HEX);
//  Serial.print(" ");
//  myCAM.rdSensorReg16_8(0x3a00,&reg_val);
//  Serial.print("AEC Mode: ");
//  Serial.print(reg_val, HEX);
//  Serial.print(" ");
//  myCAM.rdSensorReg16_8(0x3a02,&reg_val);
//  Serial.print("Max Exposure:");
//  Serial.print(reg_val, HEX);
//  Serial.print(" ");
//  myCAM.rdSensorReg16_8(0x3a03,&reg_val);
//  Serial.print("");
//  Serial.print(reg_val, HEX);
//  Serial.print(" ");
//  myCAM.rdSensorReg16_8(0x3a04,&reg_val);
//  Serial.print("");
//  Serial.println(reg_val, HEX);
  //myCAM.wrSensorReg16_8(0x3a00, 0x79);


  // check and create current year folder
  datetime = RTC.now();
  sprintf(year_filename, "%04d", datetime.year());
  if ( !SD.exists(year_filename) ) {
    Serial.print("Creating folder: ");
    Serial.println(year_filename);
    SD.mkdir(year_filename);
  }

  // check and create current month folder
  sprintf(month_filename, "%04d/%02d", datetime.year(), datetime.month());
  if ( !SD.exists(month_filename) ) {
    Serial.print("Creating folder: ");
    Serial.println(month_filename);
    SD.mkdir(month_filename);
  }

  // check and create current day folder
  sprintf(day_filename, "%04d/%02d/%02d", datetime.year(), datetime.month(), datetime.day());
  if ( !SD.exists(day_filename) ) {
    Serial.print("Creating folder: ");
    Serial.println(day_filename);
    SD.mkdir(day_filename);
  }

  sprintf(filename, "%04d/%02d/%02d/%02d_%02d_%02d.jpg", datetime.year(), datetime.month(), datetime.day(), datetime.hour(), datetime.minute(), datetime.second());
  
  Serial.println(filename);
  
  // If day time, blink the led
  if ((sunset_hour > datetime.hour()) && (sunrise_hour < datetime.hour())) {
    if (night_mode == true) {
     set_night_mode(Night_Mode_Off); 
    }
    night_mode = false;
    //digitalWrite(PWR_Relay, HIGH); // external power off
    blink_led(300,1);    
  }
  else {
    if (night_mode == false) {
      set_night_mode(Night_Mode_On);
    }
    night_mode = true;
    //digitalWrite(PWR_Relay, LOW); //external power on
  }
  
  // flush and clear fifo
  myCAM.flush_fifo();
  myCAM.clear_fifo_flag();
  myCAM.OV5642_set_JPEG_size(OV5642_2592x1944);
  
  // Start capture
  Serial.println("start capture.");

  // turn IR flash on
  if (night_mode == true) {
   digitalWrite(IR_Relay, HIGH); 
  }

  delay(250);
  myCAM.start_capture();
  while ( !myCAM.get_bit(ARDUCHIP_TRIG, CAP_DONE_MASK)); 
  
  delay(1000);
  
  // turn off flash
  digitalWrite(IR_Relay, LOW);
  Serial.println("CAM Capture Done.");
  
  read_fifo_burst(myCAM); // Save image to SD card
  
  myCAM.clear_fifo_flag(); // Clear the capture done flag

  delay(sleep_time);
}

/*
 * Blink the led defined by variable led_pin
 * @param delay_time The total time of one off and on cycle
 * @param blink_times Number of times to blink the led
 * @return NULL
 */
void blink_led(int delay_time, int blink_times) {
  for(int i = 0; i < blink_times; i++) {
    digitalWrite(led_pin, HIGH);
    delay(delay_time/2);
    digitalWrite(led_pin, LOW);
    delay(delay_time/2);
  }
}
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

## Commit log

2019-07-10 added 3d object files
    [bracket_bottom.skp, bracket_bottom.stl, bracket_bottom_v2.skp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]
2019-07-10 added current scripts and arduino firmware
2019-07-11 camera spec sheets added
2019-07-16 Led flash setup for night mode
2019-07-16 led flash refined
2020-07-08 updates for mac 2020
    [12v_stepper_case.FCStd, 12v_stepper_case.stl, 12v_stepper_case_lid.FCStd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]
2021-01-31 updates for 2020
    [Mac2020.csv]
2021-08-21 added 3d cad for case and kicad pcb files for mk5
    [AAA Batterie.step, Button.FCStd, Button.step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]
2022-03-23 camera self test working
2022-04-05 camera stream and capture working
2022-04-24 hardward bug fixes
    [SailCam_MK5.kicad_pcb, SailCam_MK5_Micro.sch, SailCam_MK5_MicroSD.sch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]
2022-05-22 many many update
    [SailCamMK5_BoatCase_Back.stl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]
2022-07-29 post 2022 video processing
    [Mac2022.csv]
2022-08-11 case updates
    [SailCamMK5_BoatCase_Bottom.stl, SailCamMK5_BoatCase_Top.stl]
2022-08-22 boat case updated
    [SailCamMK5_BoatCase_Back.stl, SailCamMK5_BoatCase_Back_Cutout.stl, SailCamMK5_BoatCase_Bottom.stl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]
2023-04-22 camera settings update

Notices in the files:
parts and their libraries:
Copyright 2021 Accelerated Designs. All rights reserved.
